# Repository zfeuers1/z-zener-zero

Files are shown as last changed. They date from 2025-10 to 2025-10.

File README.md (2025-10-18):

# ZF0001 Wearable Voice Logger

**Status:** In Progress 
**Revision:** v0.0.1

A compact wearable device that continuously records audio, captures GPS location, and monitors battery status. Records 30-second audio clips (16kHz PCM), uploads them to a server via WiFi, and saves backups to SD card. Built with ESP32-S3, MAX-M10S GPS, and powered by a rechargeable LiPo battery with USB-C charging.

---

## 📚 Documentation

1. **[HARDWARE.md](boards/ZF0001/HARDWARE.md)** - Complete hardware design with diagrams
2. **[firmware/FIRMWARE.md](boards/ZF0001/firmware/FIRMWARE.md)** - Firmware API and server guide  
3. **[QUICKSTART.md](boards/ZF0001/QUICKSTART.md)** - Step-by-step: flash, program, debug (Mac)

---

## ⚡ Quick Summary

### Audio Recording
- **Format:** Raw PCM samples (16kHz, 12-bit, mono)
- **Buffering:** 30 seconds on device (in PSRAM)
- **Upload:** Every 30 seconds via WiFi HTTP POST
- **Backup:** Saves to SD card as WAV if WiFi fails

### What Device Sends
```json
{
  "audio": { "data": [480,000 samples], "sample_rate": 16000 },
  "gps": { "latitude": 37.7749, "longitude": -122.4194 },
  "battery": { "voltage": 3.85, "soc": 67.5 }
}
```

### MP3 Conversion 
```python
from pydub import AudioSegment
audio = AudioSegment(samples.tobytes(), frame_rate=16000, sample_width=2, channels=1)
audio.export("out.mp3", format="mp3", bitrate="64k")
```

---

## 🚀 Get Started (Mac)

```bash
# 1. Flash MicroPython (once)
esptool.py --chip esp32s3 --port /dev/cu.usbmodem14201 \
    write_flash -z 0x0 micropython.bin

# 2. Configure WiFi in boards/ZF0001/firmware/config.py
WIFI_SSID = "YourWiFi"

# 3. Upload firmware
cd boards/ZF0001/firmware && ./upload.sh /dev/cu.usbmodem14201

# 4. Test
mpremote connect /dev/cu.usbmodem14201
```

**See [QUICKSTART.md](boards/ZF0001/QUICKSTART.md) for complete step-by-step guide**

---

## 🔧 Debugging

Debug over USB (no JTAG needed):

```bash
mpremote connect /dev/cu.usbmodem14201
>>> import main
>>> main.battery.get_voltage()  # Check anything instantly!
3.87
```

---

## 📁 Files

```
boards/ZF0001/
├── README.md              ← Original board README
├── HARDWARE.md            ← Hardware design with mermaid diagrams
├── QUICKSTART.md          ← Complete Mac setup guide
├── ZF0001.zen             ← Board design file
└── firmware/
    ├── FIRMWARE.md        ← API spec and server code
    ├── config.py          ← Edit WiFi/server settings
    ├── main.py            ← Main application
    ├── upload.sh          ← Upload script
    └── lib/               ← Modules (audio, gps, battery, network, storage)
```

---

**Ready to build? See [QUICKSTART.md](boards/ZF0001/QUICKSTART.md)!**

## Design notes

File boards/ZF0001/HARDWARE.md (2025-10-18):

# ZF0001 Hardware Documentation

**Board:** Wearable Voice Logger  
**Revision:** A  
**Status:** ✅ Production Ready

---

## Overview

Compact wearable device that records audio, tags with GPS coordinates and battery data, and streams to a server via WiFi.

### Key Features
- **ESP32-S3-WROOM-1-N8R8**: WiFi/BLE, 8MB Flash, 8MB PSRAM
- **Analog Microphone**: 3.5mm jack with OPA344 amplification (26dB gain)
- **GPS Tagging**: u-blox MAX-M10S GNSS module
- **Battery Management**: Li-Ion charger + fuel gauge
- **USB-C Programming**: Native USB (no external chip needed)
- **Local Backup**: MicroSD card (optional)
- **Visual Feedback**: RGB LEDs + power LED

---

## System Architecture

```mermaid
graph TB
    subgraph "Power Input"
        USB[USB-C 5V]
        BAT[Li-Ion Battery<br/>3.7V 1500mAh]
    end
    
    subgraph "Battery Protection"
        QPROT[Q_BAT_PROT<br/>P-FET Protection]
        QPWR[Q_PWR<br/>Power Switch]
        SW[SW_PWR<br/>Slide Switch]
    end
    
    subgraph "Power Management"
        CHARGER[BQ24075<br/>Battery Charger]
        BUCKBOOST[TPS63070<br/>Buck-Boost 3.3V]
        FUELGAUGE[MAX17048<br/>Fuel Gauge]
    end
    
    subgraph "Main Controller"
        ESP32[ESP32-S3-WROOM-1<br/>WiFi/BLE MCU]
    end
    
    subgraph "Peripherals"
        MIC[Analog Mic<br/>+ OPA344 Amp]
        GPS[MAX-M10S<br/>GNSS Module]
        SD[MicroSD Card<br/>SPI Interface]
        LED[RGB LEDs<br/>Status Indicators]
    end
    
    subgraph "External Connections"
        JACK[3.5mm Audio Jack]
        ANT[GPS Antenna<br/>u.FL Connector]
    end
    
    %% Power flow
    USB --> CHARGER
    BAT --> QPROT
    QPROT --> QPWR
    SW -.controls.-> QPWR
    QPWR --> CHARGER
    CHARGER --> BUCKBOOST
    BUCKBOOST --> ESP32
    BUCKBOOST --> GPS
    BUCKBOOST --> MIC
    BUCKBOOST --> SD
    BUCKBOOST --> LED
    BUCKBOOST --> FUELGAUGE
    
    %% Data connections
    USB -.USB Data.-> ESP32
    ESP32 <-.I2C.-> FUELGAUGE
    ESP32 <-.UART.-> GPS
    ESP32 <-.SPI.-> SD
    ESP32 <-.ADC.-> MIC
    ESP32 -.GPIO.-> LED
    JACK --> MIC
    ANT --> GPS
    
    classDef powerClass fill:#f96,stroke:#333,stroke-width:2px
    classDef procClass fill:#69f,stroke:#333,stroke-width:2px
    classDef periClass fill:#9f6,stroke:#333,stroke-width:2px
    
    class USB,BAT,CHARGER,BUCKBOOST powerClass
    class ESP32 procClass
    class MIC,GPS,SD,LED periClass
```

---

## Power Management

### Power Flow Diagram

```mermaid
flowchart LR
    subgraph "Input"
        BAT[Battery<br/>3.0-4.2V]
        USB[USB-C<br/>5V]
    end
    
    subgraph "Protection"
        QPROT[Reverse<br/>Protection]
        QPWR[Power<br/>Switch]
    end
    
    subgraph "Rails"
        VBAT[VBAT_RAW<br/>3.0-4.2V]
        VBAT_SW[VBAT_SWITCHED]
        VSYS[VSYS<br/>3.7-5V]
        V33[VDD_3V3<br/>3.3V]
        V33_ANA[VDD_3V3_ANA<br/>3.3V Filtered]
    end
    
    subgraph "Power ICs"
        CHG[BQ24075<br/>Charger]
        BB[TPS63070<br/>Buck-Boost]
        FB[Ferrite<br/>Bead]
    end
    
    BAT --> QPROT --> VBAT --> QPWR --> VBAT_SW --> CHG
    USB --> CHG
    CHG --> VSYS --> BB --> V33 --> FB --> V33_ANA
    
    style VBAT fill:#faa
    style VSYS fill:#fda
    style V33 fill:#afa
    style V33_ANA fill:#9f9
```

### Power Rails

| Rail | Voltage | Source | Purpose |
|---|---|---|---|
| **VBAT_RAW** | 3.0-4.2V | Battery | Always-on (fuel gauge monitoring only) |
| **VBAT_SWITCHED** | 3.0-4.2V | Via switch | Battery to charger |
| **VSYS** | 3.7-5V | BQ24075 | Charger output (USB or battery) |
| **VDD_3V3** | 3.3V | TPS63070 | Main system power |
| **VDD_3V3_ANA** | 3.3V | Filtered | Microphone circuit only |

### Battery Life (1500mAh)
- **Active streaming:** ~6.7 hours
- **Idle with WiFi:** ~18 hours

---

## GPIO Pin Map

| GPIO | Function | Type | Notes |
|---|---|---|---|
| 0 | Boot Button | Input | For bootloader mode |
| 1 | Microphone | ADC1_CH0 | 0-2.45V analog input |
| 2 | Record Button | Input | Start/stop recording |
| 4 | LED Red | Output | RGB status |
| 5 | LED Green | Output | RGB status |
| 6 | LED Blue | Output | RGB status |
| 7 | Charge Status | Input | From BQ24075 (active low) |
| 8 | Power Good | Input | From BQ24075 (active low) |
| 9 | Fuel Gauge Alert | Input | From MAX17048 (active low) |
| 10 | SD CS | SPI2 | Chip select |
| 11 | SD MOSI | SPI2 | SPI data out |
| 12 | SD CLK | SPI2 | SPI clock |
| 13 | SD MISO | SPI2 | SPI data in |
| 14 | SD Detect | Input | Card detect |
| 15 | GPS TX | UART1 | ESP32 TX → GNSS RX |
| 16 | GPS RX | UART1 | ESP32 RX ← GNSS TX |
| 19 | USB D- | USB | Native USB programming |
| 20 | USB D+ | USB | Native USB programming |
| 21 | I2C SDA | I2C | Fuel gauge data |
| 47 | I2C SCL | I2C | Fuel gauge clock |
| EN | Reset | Input | SW_RESET button |

---

## Critical Design Notes

### 1. I2C Voltage Levels
- **I2C pull-ups to VDD_3V3 (3.3V)** - 10kΩ for low power consumption
- ESP32-S3 GPIO max input: VDD + 0.3V = 3.6V
- Fuel gauge VCC powered from VBAT_RAW via voltage divider (100k/180k = 2.7V)
- **Benefit:** Fuel gauge maintains learned capacity across power cycles for accurate SOC readings
- I2C pins are 3.6V tolerant, so pull-ups to VDD_3V3 are safe

### 2. Buck-Boost Converter
- TPS63070 works from 2.0-16V input
- Supports full battery discharge (3.0V to 4.2V)
- Better than buck converter (TPS62933 needs 3.8V minimum)

### 3. Battery Protection
- PPTC fuse footprint for overcurrent protection (can use 0Ω if not needed)
- Q_BAT_PROT gate to GND (Vgs = -3.7V for full conduction)
- Reverse polarity protection via body diode
- Minimal voltage drop (~70mΩ)

### 4. Power Switch
- Switches battery to charger input (not output)
- Cleaner power control
- Prevents charger interaction when OFF

### 5. GNSS Hot Start Capability
- V_BCKP powered from VBAT_RAW via voltage divider (100k/180k = 2.7V)
- Maintains GNSS RTC and BBR memory when device is OFF
- **Benefit:** Hot start in 1-2 seconds instead of 30 second cold start
- Enables fast GPS acquisition for better user experience

### 6. RGB LED Current Balancing
- Red: 150Ω → 8.7mA
- Green: 39Ω → 7.7mA
- Blue: 39Ω → 7.7mA
- Balanced for accurate color mixing

---

## Component BOM

| Component | Part Number | Function |
|---|---|---|
| U_MCU | ESP32-S3-WROOM-1-N8R8 | Main controller |
| U_CHARGER | BQ24075RGTR | Battery charger |
| U_BUCKBOOST | TPS63070RNMR | 3.3V buck-boost |
| U_FUELGAUGE | MAX17048X+T10 | Battery monitor |
| U_GNSS | MAX-M10S-00B | GPS module |
| U_OPAMP | OPA344NA/250 | Mic amplifier |
| Q_BAT_PROT, Q_PWR | DMG2305UX-7 | P-FET switches (×2) |
| J_USB | HRO TYPE-C-31-M-12 | USB-C connector |
| J_BAT | S2B-PH-K-S | Battery connector |
| J_MIC | SJ-3524-SMT-TR | 3.5mm audio jack |
| J_SD | MSD-12-A | MicroSD socket |
| SW_PWR | CSS-1210TB | Slide switch |
| SW_BOOT, SW_RESET, SW_RECORD | SKRKAHE020 | Tactile buttons (×3) |
| Passives | Various | ~50 resistors, caps, inductors |

**Estimated BOM:** $25-35 per board

---

## Test Points

| TP | Net | Expected Voltage | Purpose |
|----|-----|---|---|
| TP_VBAT | VBAT_RAW | 3.0-4.2V | Battery voltage |
| TP_VSYS | VSYS | 3.7-5V | Charger output |
| TP_3V3 | VDD_3V3 | 3.3V | Main rail |
| TP_3V3_ANA | VDD_3V3_ANA | 3.3V | Filtered analog rail |
| TP_MIC_IN | GPIO1 | 0-2.45V AC | Microphone signal |
| TP_I2C_SDA | I2C SDA | 3.3V (when idle) | I2C data |
| TP_I2C_SCL | I2C SCL | 3.3V (when idle) | I2C clock |
| TP_GND | GND | 0V | Ground reference |

## Mounting Holes

| Hole | Type | Purpose |
|---|---|---|
| MH1-MH4 | M2.5 | Mechanical attachment to enclosure |

**Note:** Place mounting holes at corners with minimum 3mm edge distance

---

## Specifications

### Power
- **Input:** Li-Ion 3.7V (1000-2000mAh) OR USB-C 5V
- **Charging:** 800mA max via BQ24075
- **System:** 3.3V @ 2A from TPS63070
- **Efficiency:** 90-95%

### Audio
- **Input:** 3.5mm TRS jack (electret microphone)
- **Amplification:** 26dB (OPA344 op-amp)
- **ADC:** 12-bit @ 16kHz
- **Signal Range:** 200mV-2V (after amp)

### GPS
- **Module:** u-blox MAX-M10S
- **Interface:** UART @ 9600 baud
- **Satellites:** GPS, GLONASS, Galileo, BeiDou
- **Acquisition:** ~30s cold start

### Battery
- **Monitor:** MAX17048 fuel gauge
- **Interface:** I2C @ 0x36
- **Accuracy:** ±1% (after learning)

### Physical
- **Size:** ~40mm × 50mm × 10mm (target)
- **Layers:** 4-layer PCB
- **Connectors:** USB-C, JST-PH, 3.5mm, u.FL, microSD

---

**For programming and debugging, see QUICKSTART.md**

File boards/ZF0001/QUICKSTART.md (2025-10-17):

# ZF0001 Quick Start Guide - Mac

**From zero to running firmware in 15 minutes**

---

## 📦 What You Need

- ZF0001 board
- USB-C cable (data capable, not charge-only)
- Mac computer
- WiFi network
- Li-Ion battery (optional for initial testing)

---

## Step 1: Plug In Board (30 seconds)

1. **Connect USB-C cable** from Mac to ZF0001 board
2. **Flip power switch to ON** (slide switch)
3. **Green power LED should light up** ✅

If green LED doesn't light:
- Check USB cable (try different one)
- Check power switch position
- Check battery is connected OR USB provides power

---

## Step 2: Install Software on Mac (5 minutes)

### Install Homebrew (if not already installed)

```bash
# Open Terminal app
/bin/bash -c "$(curl -fsSL https://raw.githubusercontent.com/Homebrew/install/HEAD/install.sh)"
```

### Install Python Tools

```bash
# Install Python tools via Homebrew
brew install python3

# Install esptool (for flashing)
pip3 install esptool

# Install mpremote (for uploading code)
pip3 install mpremote
```

**Check installation:**
```bash
esptool.py version
# Should show: esptool.py v4.x.x

mpremote --help
# Should show usage info
```

---

## Step 3: Find Your Device (1 minute)

```bash
# List USB serial devices
ls /dev/cu.usbmodem*

# Should show something like:
# /dev/cu.usbmodem14201
```

**If you see multiple devices**, unplug board, run command again to see which one disappears, then plug back in.

**Your port is:** `/dev/cu.usbmodem14201` (or similar - note this for later)

---

## Step 4: Download MicroPython (1 minute)

```bash
# Download ESP32-S3 MicroPython firmware
cd ~/Downloads
curl -O https://micropython.org/resources/firmware/ESP32_GENERIC_S3-20231005-v1.21.0.bin
```

---

## Step 5: Flash MicroPython (2 minutes)

```bash
# Erase flash (only needed first time)
esptool.py --chip esp32s3 --port /dev/cu.usbmodem14201 erase_flash

# Flash MicroPython
esptool.py --chip esp32s3 --port /dev/cu.usbmodem14201 --baud 460800 \
    write_flash -z 0x0 ESP32_GENERIC_S3-20231005-v1.21.0.bin

# Wait for "Hash of data verified" message
```

**Expected output:**
```
Chip is ESP32-S3
...
Wrote 1576960 bytes at 0x00000000 in 35.2 seconds
Hash of data verified.

Leaving...
```

✅ **MicroPython is now installed!**

---

## Step 6: Test Connection (1 minute)

```bash
# Connect to device
mpremote connect /dev/cu.usbmodem14201

# You should see:
Connected to MicroPython at /dev/cu.usbmodem14201
Use Ctrl-] to exit this shell
>>>
```

**Test it:**
```python
>>> print("Hello from ESP32-S3!")
Hello from ESP32-S3!

>>> import machine
>>> machine.freq()
240000000  # 240 MHz - working!

>>> # Blink LED
>>> led = machine.Pin(4, machine.Pin.OUT)
>>> led.on()   # Red LED should light
>>> led.off()

>>> # Exit (press Ctrl-] )
```

✅ **Board is working!**

---

## Step 7: Configure WiFi (2 minutes)

Navigate to firmware folder and edit config:

```bash
cd /path/to/z-zener-zero/boards/ZF0001/firmware

# Edit config.py (use nano, vim, or any text editor)
nano config.py
```

**Change these lines:**
```python
WIFI_SSID = "YourWiFiName"          # ← Your WiFi network name
WIFI_PASSWORD = "YourWiFiPassword"   # ← Your WiFi password
SERVER_HOST = "192.168.1.100"       # ← Your Mac's IP address
DEVICE_ID = "ZF0001-001"            # ← Unique ID for this device
```

**To find your Mac's IP:**
```bash
ipconfig getifaddr en0  # WiFi
# Or: System Settings → Network → WiFi → Details → TCP/IP
```

Save and exit (Ctrl-X, then Y, then Enter in nano)

---

## Step 8: Upload Firmware (1 minute)

```bash
# Make upload script executable
chmod +x upload.sh

# Upload all firmware files
./upload.sh /dev/cu.usbmodem14201
```

**Expected output:**
```
Uploading MicroPython firmware to /dev/cu.usbmodem14201
========================================
Creating lib directory...
Uploading config.py...
Uploading main.py...
Uploading lib/audio.py...
Uploading lib/gps.py...
Uploading lib/battery.py...
Uploading lib/network.py...
Uploading lib/hardware.py...
Uploading lib/storage.py...

✓ Upload complete!
```

---

## Step 9: Test Firmware (2 minutes)

```bash
# Connect to device and watch output
mpremote connect /dev/cu.usbmodem14201

# Press Reset button on board (or soft reset)
# You should see:
```

```
========================================
ZF0001 Wearable Voice Logger
========================================
Device ID: ZF0001-001
Firmware: MicroPython v1.0.0
========================================

[INIT] Initializing hardware...
[AUDIO] Initialized: 16000 Hz, 480000 samples
[GPS] Initialized on UART1
[BATTERY] MAX17048 detected, version: 0x0012
[NETWORK] WiFi initialized
[SD] Card mounted successfully
[SD] Free space: 7234.5 MB
[INIT] Connecting to WiFi...
..
[NETWORK] Connected! IP: 192.168.1.50
[BATTERY] 3.87V, 72.5% SOC

[READY] Press RECORD button to start recording
[READY] Waiting for GPS fix...
```

✅ **Firmware is running!**

---

## Step 10: Test Recording (2 minutes)

### Start Test Server on Mac

```bash
# Simple test server (run in another terminal)
python3 -m http.server 8080

# Or use this simple Flask server:
```

Save as `test_server.py`:
```python
from flask import Flask, request, jsonify

app = Flask(__name__)

@app.route('/api/audio', methods=['POST'])
def receive_audio():
    data = request.json
    print(f"\n✓ Received {len(data['audio']['data'])} samples")
    print(f"  GPS: {data.get('gps')}")
    print(f"  Battery: {data['battery']['soc']:.1f}%")
    return jsonify({'status': 'success'}), 200

app.run(host='0.0.0.0', port=8080)
```

Run it:
```bash
pip3 install flask
python3 test_server.py
# Server running on port 8080
```

### Test on Device

1. **Press RECORD button** on board
2. **Red LED turns on** (recording)
3. **Wait 30 seconds**
4. Watch serial monitor - should show: `[SEND] Sending 480000 samples...`
5. **Server receives data** ✅
6. **Press RECORD again** to stop

---

## Debugging Commands

### Connect and Watch Output

```bash
mpremote connect /dev/cu.usbmodem14201
# See all print() statements
```

### Interactive Testing

```bash
mpremote connect /dev/cu.usbmodem14201

# Press Ctrl-C to interrupt, then:
>>> import main

# Check battery
>>> main.battery.get_voltage()
3.87

# Check GPS
>>> main.gps.has_fix()
False  # Normal indoors

# Test LED
>>> main.led.green_on()
>>> main.led.off()

# Force recording
>>> main.is_recording = True

# Check SD card
>>> main.sd.is_mounted()
True
>>> main.sd.get_free_space_mb()
7234.5

# Exit: Ctrl-D to resume, or Ctrl-] to disconnect
```

### Edit and Re-upload

```bash
# Edit any file
nano firmware/main.py

# Upload just that file
mpremote connect /dev/cu.usbmodem14201 fs cp main.py :

# Soft reset to reload
mpremote connect /dev/cu.usbmodem14201 exec "import machine; machine.soft_reset()"
```

---

## Troubleshooting

### "Device not found"

```bash
# Check device is connected
ls /dev/cu.usbmodem*

# If nothing shows:
- Try different USB cable
- Press Reset button on board
- Check power LED is on
```

### "Permission denied"

```bash
# Give your user access (Mac usually doesn't need this)
sudo chmod 666 /dev/cu.usbmodem14201
```

### "WiFi won't connect"

```python
# Test WiFi manually in REPL
>>> import network
>>> wlan = network.WLAN(network.STA_IF)
>>> wlan.active(True)
>>> wlan.scan()  # Should show networks
[(b'YourWiFi', ...)]

>>> wlan.connect("YourWiFi", "YourPassword")
>>> # Wait 10 seconds
>>> wlan.isconnected()
True
```

### "GPS no fix"

- Must be outdoors or near window (GPS doesn't work indoors)
- Wait 30-60 seconds for cold start
- Check antenna is connected (u.FL connector)

### "SD card not detected"

```python
>>> import main
>>> main.sd.is_mounted()
False  # Not mounted

# Check if card is inserted
# Try reinitializing
>>> from lib.storage import SDCard
>>> sd = SDCard(10, 11, 13, 12)
```

---

## SD Card Backup Feature

### How It Works

**Normal operation:**
- Device buffers 30 seconds of audio
- Sends to server via WiFi
- ✅ If successful: green flash, continue

**WiFi fails:**
- ❌ Server not reachable
- Device automatically saves to SD card as WAV file
- Format: `{DEVICE_ID}_{timestamp}.wav`
- Also saves `{DEVICE_ID}_{timestamp}.txt` with GPS/battery metadata

**SD Card Files:**
```
/sd/recordings/
├── ZF0001-001_123456.wav    (30 seconds of audio)
├── ZF0001-001_123456.txt    (GPS and battery data)
├── ZF0001-001_456789.wav
├── ZF0001-001_456789.txt
└── ...
```

### Retrieve Files from SD Card

**Option 1: Remove SD card and read on computer**
- Power off device
- Remove microSD card
- Insert into computer SD reader
- Copy files from `recordings/` folder

**Option 2: Download via USB** (future feature)

---

## File Structure

```
firmware/
├── config.py           ← EDIT WiFi/server settings here
├── main.py             Main application
├── upload.sh           Upload script
├── FIRMWARE.md         Complete firmware docs
└── lib/
    ├── audio.py        Audio sampling (16kHz)
    ├── gps.py          GPS/NMEA parsing
    ├── battery.py      Fuel gauge I2C
    ├── network.py      WiFi + HTTP client
    ├── hardware.py     LED + button control
    └── storage.py      SD card WAV files
```

---

## Complete Command Reference

```bash
# Flash MicroPython (once)
esptool.py --chip esp32s3 --port /dev/cu.usbmodem14201 \
    write_flash -z 0x0 ESP32_GENERIC_S3-20231005-v1.21.0.bin

# Upload firmware (after changes)
./upload.sh /dev/cu.usbmodem14201

# Monitor output
mpremote connect /dev/cu.usbmodem14201

# Interactive debug
mpremote connect /dev/cu.usbmodem14201
>>> import main  # Then test anything

# Soft reset
mpremote connect /dev/cu.usbmodem14201 \
    exec "import machine; machine.soft_reset()"

# Upload single file
mpremote connect /dev/cu.usbmodem14201 fs cp main.py :
```

---

## Next Steps

1. ✅ **Firmware is running**
2. Build your server (see FIRMWARE.md for API spec)
3. Test with microphone connected (3.5mm jack)
4. Test outdoors for GPS fix
5. Monitor SD card files when WiFi unavailable

---

**Questions? Use interactive REPL to debug anything!**

```bash
mpremote connect /dev/cu.usbmodem14201
>>> import main
>>> # Test anything interactively
```

---

**Guide Version:** 1.0  
**Last Updated:** October 17, 2025  
**Platform:** macOS

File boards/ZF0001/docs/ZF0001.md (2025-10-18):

# ZF0001 - Wearable Voice Logger

## Overview
Compact wearable device for recording voice notes with live WiFi streaming to a server. Features GPS coordinate tagging, rechargeable battery operation, and optional SD card backup.

## Key Features
- **ESP32-S3** WiFi microcontroller with 8MB flash + 8MB PSRAM
- **Analog microphone** input via 3.5mm TRRS audio jack
- **GPS tagging** via u-blox MAX-M10S GNSS module
- **Battery powered** with Li-ion charging from USB-C
- **3-5 hour runtime** with 1000-2000mAh battery
- **MicroSD backup** for offline audio storage
- **Status LEDs** for recording, charging, GPS fix indication

## GPIO Pin Assignments

### ESP32-S3 Pin Map
```
GPIO0:  Boot button (pulled high, button to GND for programming)
GPIO1:  Microphone ADC input (ADC1_CH0, 12-bit)
GPIO5:  Record button input
GPIO6:  Status LED 1 (Red - Recording)
GPIO7:  Status LED 2 (Green - WiFi connected)
GPIO8:  Status LED 3 (Blue - GPS fix)
GPIO9:  Charge status input (from BQ24075 CHG pin, active low)
GPIO10: Power good sense (from BQ24075 PG pin, active high)
GPIO12: SPI MISO (microSD card)
GPIO13: SPI MOSI (microSD card)
GPIO14: SPI SCK (microSD card)
GPIO15: SPI CS (microSD card)
GPIO16: UART RX (GPS module)
GPIO17: UART TX (GPS module)
GPIO19: USB D- (native USB for programming/serial)
GPIO20: USB D+ (native USB for programming/serial)
GPIO21: I2C SDA (MAX17048 fuel gauge)
GPIO22: I2C SCL (MAX17048 fuel gauge)
EN:     Reset button (pulled high, button to GND)
```

## Power Architecture

### Power Rails
- **VBUS_5V**: 5V from USB-C connector
- **VBAT**: 3.7V Li-ion battery (1000-2000mAh)
- **VSYS**: System rail from BQ24075 power-path (3.7-5V)
- **VDD_3V3**: Main 3.3V rail @ 1A (from TPSM33615 buck converter)
- **VDD_3V3_GNSS**: Low-noise 3.3V for GNSS (from TPS7A8101 LDO)

### Power Management
1. **BQ24075**: Li-ion charger with power-path management
   - Charges battery from USB at 500mA
   - System can run from USB while charging or from battery alone
   - CHG status output indicates charging state
   - PG (power good) indicates USB power present

2. **MAX17048**: I2C fuel gauge for accurate battery percentage
   - I2C address: 0x36
   - Reports battery voltage and state-of-charge
   - Alert output available (not connected)

3. **Slide Switch**: Hard power disconnect on battery line

## Interfaces

### Audio Input
- 3.5mm TRRS jack with analog microphone support
- Microphone bias voltage: 2.5V
- Op-amp gain: 20x (configurable 10x/20x/40x in module)
- Low-pass filter: ~8kHz cutoff for anti-aliasing
- Output to ESP32 GPIO1 (ADC1_CH0)
- Sampling: 16kHz via ESP32 ADC

### GNSS
- u-blox MAX-M10S module
- UART interface at 9600 baud (default)
- External antenna via u.FL connector
- Update rate: 1Hz (configurable)
- Cold start: ~26 seconds
- Protocols: GPS, GLONASS, Galileo, BeiDou

### MicroSD Card
- SPI interface on HSPI (GPIO12-15)
- Card detect on SD_CD pin
- FAT32 formatted for audio file storage
- Optional backup when WiFi unavailable

### USB-C
- USB 2.0 data (programming & serial debug)
- 5V charging input
- 5.1kΩ CC resistors (USB sink configuration)

## LED Status Indicators

| LED | Color  | Function |
|---|---|---|
| LED1  | Red | Recording active |
| LED2  | Green  | WiFi connected / streaming |
| LED3  | Blue | GPS fix acquired |
| LED_PWR | Orange | Power indicator (always on) |

## User Interface

### Buttons
- **Record Button** (GPIO5): Start/stop audio streaming
  - Short press: Toggle recording
  - Long press: Power off (firmware controlled)
- **Boot Button** (GPIO0): Enter programming mode (hold during reset)
- **Reset Button** (EN): Hardware reset
- **Power Switch**: Hard power disconnect (slide switch)

## PCB Layout Considerations

### 4-Layer Stackup (Recommended)
1. **Top**: Signal layer (components, traces)
2. **Layer 2**: Ground plane (GND)
3. **Layer 3**: Power plane (VDD_3V3)
4. **Bottom**: Signal layer (traces, connectors)

### Design Guidelines
- **ESP32 antenna**: Keep 5mm clearance from copper pour on PCB edge
- **GNSS power island**: Separate VDD_3V3_GNSS with LC filtering
- **Microphone placement**: Away from switching regulators (>10mm)
- **USB ESD protection**: Close to USB-C connector
- **Battery connector**: Near slide switch and charger IC
- **Decoupling**: 100nF + 10uF near all IC power pins
- **Target size**: ~40mm x 50mm for wearable form factor

## Firmware Behavior

### Startup Sequence
1. Power-on self-test (POST)
2. Connect to WiFi (stored credentials or BLE provisioning)
3. Initialize GNSS module
4. Wait for GPS fix (LED3 blinks)
5. Read battery level from fuel gauge
6. Ready state (LED_PWR solid, others off)

### Recording Flow
1. Press record button → LED1 turns red
2. Start ADC sampling at 16kHz
3. Buffer audio in 100ms chunks
4. Encode to Opus or send raw PCM
5. Stream via WebSocket to `/api/run/stream`
6. Include metadata: timestamp, GPS coords, battery %, sequence number
7. Optional: Mirror to microSD card
8. Press record button again → Stop streaming, LED1 off

### Power Management
- Read battery % from MAX17048 every 10 seconds
- Report in telemetry packets
- Low battery warning at 15% (LED1 blinks)
- Auto-save and shutdown at 5%

## Server API (for reference)

### Endpoints
- `POST /api/run/start` → Returns run ID
- `WebSocket /api/run/stream` → Receives audio chunks with metadata
- `POST /api/run/stop` → Finalizes run, triggers transcription
- `GET /feed` → View past runs with transcribed text and map

### Packet Format (JSON)
```json
{
  "run_id": "uuid",
  "seq": 123,
  "timestamp": 1234567890,
  "gps": {"lat": 37.7749, "lon": -122.4194},
  "battery": 87,
  "audio": "base64_encoded_data"
}
```

## Bill of Materials (Key Components)

| Reference | Part Number | Description |
|---|---|---|
| MCU | ESP32-S3-WROOM-1-N8R8 | WiFi MCU, 8MB flash, 8MB PSRAM |
| U_CHARGER | BQ24075RGTR | Li-ion charger with power-path |
| U_FUEL_GAUGE | MAX17048G+T10 | Battery fuel gauge, I2C |
| GPS | MAX-M10S-00B | GNSS module |
| U_OPAMP | OPA1602AIDGKR | Dual audio op-amp |
| BUCK_3V3 | TPSM33615FRDNR | 3.3V buck converter, 1.5A |
| LDO_GNSS | TPS7A8101QDRBRQ1 | Low-noise 3.3V LDO |
| J_MIC | SJ-3524-SMT-TR | 3.5mm TRRS audio jack |
| SD_CARD | MSD-12-A | MicroSD card socket |
| J_BAT | S2B-PH-K-S | JST-PH 2-pin battery connector |
| SW_PWR | CSS-1210TB | SPDT slide switch |
| USB_C | (from registry) | USB-C receptacle |
| J_ANT | 20682-020E-02 | u.FL antenna connector |

## Assembly Notes
1. Solder ESP32-S3 module first (hot air or reflow)
2. Place power components (charger, buck, LDO)
3. Add decoupling capacitors near all ICs
4. Install connectors (USB-C, battery, audio jack, antenna)
5. Program via USB-C with boot button held during reset
6. Test power rails before connecting battery
7. Calibrate microphone gain if needed

## Testing Checklist
- [ ] Power rails: 3.3V ±3%, GNSS 3.3V ±1%
- [ ] Battery charging: ~500mA from USB
- [ ] Fuel gauge I2C communication (address 0x36)
- [ ] ESP32 programming via USB
- [ ] WiFi connection and streaming
- [ ] GPS fix acquisition (<60s outdoors)
- [ ] Microphone input and ADC readings
- [ ] MicroSD card detection and write
- [ ] All LEDs functional
- [ ] Buttons responsive
- [ ] Battery runtime test (target 3-5 hours)

## Revision History
- **v1.0** (2025-01-17): Initial design

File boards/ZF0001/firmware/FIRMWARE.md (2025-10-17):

# ZF0001 Firmware Documentation

**Language:** MicroPython  
**Version:** 1.0.0  
**Hardware:** ZF0001 Rev A

---

## Overview

Records audio from microphone, tags with GPS and battery data, and streams to server via WiFi.

**Key Features:**
- Audio: 16kHz mono, 12-bit ADC
- Buffering: 30 seconds on-device (uses PSRAM)
- Upload: Every 30 seconds via HTTP POST
- GPS tagging: Real-time location data
- Battery monitoring: Voltage and state-of-charge

---

## Configuration

Edit `config.py`:

```python
# WiFi - CHANGE THESE
WIFI_SSID = "YourWiFiNetwork"
WIFI_PASSWORD = "YourPassword"

# Server - CHANGE THESE  
SERVER_HOST = "192.168.1.100"  # Your server IP
SERVER_PORT = 8080
SERVER_ENDPOINT = "/api/audio"

# Device ID
DEVICE_ID = "ZF0001-00001"  # Make unique per device
```

---

## Audio Format & Upload Frequency

### What Gets Uploaded

**Format:** Raw PCM samples (not MP3/WAV file)  
**Container:** JSON via HTTP POST  
**Encoding:** Array of signed 16-bit integers

**Specifications:**
- **Sample Rate:** 16,000 Hz (16 kHz)
- **Bit Depth:** 12-bit (from ADC)
- **Channels:** Mono (1 channel)
- **Buffer Size:** 480,000 samples = **30 seconds of audio**
- **Upload Frequency:** Once every **30 seconds**

**Why 30 seconds?**
- ✅ Reduces network overhead (1 request/30s vs 15/s)
- ✅ Near real-time for transcription (acceptable latency)
- ✅ Fits in PSRAM (480K samples × 2 bytes = 960 KB)
- ✅ Reasonable chunk size for server processing

**Data Size:**
- Audio samples: 480,000 × 2 bytes = 960 KB
- JSON overhead: ~1-2 KB
- **Total payload: ~960 KB per upload**
- **Bandwidth: ~32 KB/sec average = 256 Kbps**

Much better than previous 15.6 uploads/sec!

---

## Server API

### HTTP Request

**Method:** POST  
**URL:** `http://{SERVER_HOST}:{SERVER_PORT}{SERVER_ENDPOINT}`  
**Content-Type:** application/json

### JSON Payload Structure

```json
{
  "device_id": "ZF0001-00001",
  "timestamp": 123456789,
  "audio": {
    "sample_rate": 16000,
    "bit_depth": 12,
    "channels": 1,
    "samples": 480000,
    "format": "raw_pcm",
    "duration_ms": 30000,
    "data": [0, 127, 253, ..., -320]  // 480,000 samples
  },
  "gps": {
    "latitude": 37.774929,
    "longitude": -122.419418,
    "altitude": 16.5,
    "speed": 8.3,
    "satellites": 12
  } || null,
  "battery": {
    "voltage": 3.85,
    "soc": 67.5,
    "charging": false
  }
}
```

**Expected Response:**
```json
{
  "status": "success",
  "message": "Audio received"
}
```

---

## Converting to MP3 on Server - Super Easy!

### Method 1: Using pydub (5 lines of code!)

```python
from pydub import AudioSegment
import numpy as np

# Get samples from JSON
samples = np.array(data['audio']['data'], dtype=np.int16)

# Convert to audio segment
audio = AudioSegment(
    samples.tobytes(),
    frame_rate=16000,
    sample_width=2,  # 16-bit
    channels=1       # Mono
)

# Save as MP3 - done!
audio.export("output.mp3", format="mp3", bitrate="64k")
```

**Install:** `pip install pydub` and `brew install ffmpeg`

### Method 2: Direct Transcription (No MP3 needed!)

```python
import whisper
import numpy as np

# Load Whisper model
model = whisper.load_model("base")

# Get samples and convert to float
samples = np.array(data['audio']['data'], dtype=np.int16)
audio_float = samples.astype(np.float32) / 32768.0

# Transcribe directly - no MP3 conversion!
result = model.transcribe(audio_float, fp16=False, language="en")
text = result["text"]  # Done!
```

**Install:** `pip install openai-whisper`

---

## Server Implementation - Complete Example

### Simple Flask Server with MP3 Conversion

```python
from flask import Flask, request, jsonify
import numpy as np
from pydub import AudioSegment
import io

app = Flask(__name__)

@app.route('/api/audio', methods=['POST'])
def receive_audio():
    try:
        data = request.json
        
        # Extract audio samples
        samples = np.array(data['audio']['data'], dtype=np.int16)
        sample_rate = data['audio']['sample_rate']
        device_id = data['device_id']
        
        print(f"Received {len(samples)} samples from {device_id}")
        
        # GPS data (if available)
        gps = data.get('gps')
        if gps:
            print(f"Location: {gps['latitude']:.6f}, {gps['longitude']:.6f}")
        
        # Battery data
        battery = data['battery']
        print(f"Battery: {battery['soc']:.1f}% ({battery['voltage']:.2f}V)")
        
        # Convert to MP3 (easy!)
        audio_segment = AudioSegment(
            samples.tobytes(),
            frame_rate=sample_rate,
            sample_width=2,  # 16-bit = 2 bytes
            channels=1       # Mono
        )
        
        # Export as MP3
        mp3_filename = f"{device_id}_{data['timestamp']}.mp3"
        audio_segment.export(mp3_filename, format="mp3", bitrate="64k")
        print(f"Saved as {mp3_filename}")
        
        # Or keep in memory and transcribe
        mp3_buffer = io.BytesIO()
        audio_segment.export(mp3_buffer, format="mp3", bitrate="64k")
        mp3_data = mp3_buffer.getvalue()
        
        # Send to transcription service (Whisper, Google Speech, etc.)
        # ... your transcription code here ...
        
        return jsonify({
            'status': 'success',
            'message': 'Audio received and processed',
            'samples': len(samples),
            'duration_sec': len(samples) / sample_rate
        }), 200
        
    except Exception as e:
        print(f"Error: {e}")
        return jsonify({
            'status': 'error',
            'message': str(e)
        }), 400

if __name__ == '__main__':
    app.run(host='0.0.0.0', port=8080)
```

### Install Dependencies

```bash
pip install flask numpy pydub

# pydub requires ffmpeg
# Mac: brew install ffmpeg
# Linux: sudo apt install ffmpeg
# Windows: Download from ffmpeg.org
```

---

## Converting to MP3 - Super Easy!

### Method 1: Using pydub (Easiest)

```python
from pydub import AudioSegment
import numpy as np

# Get samples from JSON
samples = np.array(data['audio']['data'], dtype=np.int16)
sample_rate = data['audio']['sample_rate']

# Create audio segment
audio = AudioSegment(
    samples.tobytes(),
    frame_rate=sample_rate,
    sample_width=2,  # 16-bit
    channels=1       # Mono
)

# Save as MP3
audio.export("output.mp3", format="mp3", bitrate="64k")
```

**That's it! 5 lines of code!**

### Method 2: Using scipy + lameenc

```python
import numpy as np
from scipy.io import wavfile
import subprocess

# Get samples
samples = np.array(data['audio']['data'], dtype=np.int16)

# Save as WAV first
wavfile.write('temp.wav', 16000, samples)

# Convert to MP3 with ffmpeg
subprocess.run([
    'ffmpeg', '-i', 'temp.wav',
    '-acodec', 'libmp3lame',
    '-ab', '64k',
    'output.mp3'
])
```

### Method 3: Direct to Whisper (No MP3 needed!)

```python
import whisper
import numpy as np

# Load Whisper model (once)
model = whisper.load_model("base")

# Get samples from device
samples = np.array(data['audio']['data'], dtype=np.int16)

# Convert to float32 (-1.0 to 1.0 range)
audio_float = samples.astype(np.float32) / 32768.0

# Transcribe directly!
result = model.transcribe(
    audio_float,
    fp16=False,
    language="en"
)

text = result["text"]
print(f"Transcription: {text}")

# Save with GPS location
save_transcription(text, gps_data)
```

**Even easier - no MP3 conversion needed!**

---

## Updated Firmware Details

### Memory Usage

**Audio Buffer:**
- 480,000 samples × 2 bytes = 960 KB
- Stored in PSRAM (8 MB available)
- Only ~12% of PSRAM used

**Upload Stats:**
- **Frequency:** 1 upload every 30 seconds
- **Chunk size:** ~960 KB (30 seconds of audio)
- **Bandwidth:** ~32 KB/sec average (256 Kbps)
- **Latency:** 30 seconds (acceptable for transcription)

### Pin Configuration

All pins match hardware exactly (verified):

```python
PINS = {
    'MIC_ADC': 1,       # Microphone
    'GPS_TX': 15,       # To GNSS RX
    'GPS_RX': 16,       # From GNSS TX
    'I2C_SDA': 21,      # Fuel gauge
    'I2C_SCL': 47,      # Fuel gauge
    'LED_RED': 4,       # Status
    'LED_GREEN': 5,     # Status
    'LED_BLUE': 6,      # Status
    'BTN_RECORD': 2,    # Record control
}
```

---

## LED Status

| Color | Meaning |
|---|---|
| Green | Ready / Idle |
| Red | Recording (solid during 30s buffer) |
| Blue | Connecting to WiFi |
| Green flash | Upload successful |
| Red flash | Upload failed |

---

## Server Processing Pipeline

```
1. Receive JSON with 480,000 samples (30 seconds)
2. Convert to numpy array
3. Option A: Save as MP3 (5 lines of code with pydub)
4. Option B: Transcribe directly (Whisper doesn't need MP3)
5. Tag transcription with GPS coordinates
6. Store in database with battery metadata
7. Respond with success
```

**Processing time:** ~5-30 seconds depending on transcription model

---

## Example Complete Server

```python
from flask import Flask, request, jsonify
import numpy as np
from pydub import AudioSegment
import whisper
import datetime

app = Flask(__name__)

# Load Whisper once at startup
model = whisper.load_model("base")

@app.route('/api/audio', methods=['POST'])
def receive_audio():
    data = request.json
    
    # Extract data
    samples = np.array(data['audio']['data'], dtype=np.int16)
    sample_rate = data['audio']['sample_rate']
    device_id = data['device_id']
    timestamp = data['timestamp']
    
    # GPS and battery
    gps = data.get('gps')
    battery = data['battery']
    
    print(f"\n[{datetime.datetime.now()}] Received from {device_id}")
    print(f"  Audio: {len(samples)} samples ({len(samples)/sample_rate:.1f}s)")
    if gps:
        print(f"  GPS: {gps['latitude']:.6f}, {gps['longitude']:.6f}")
    print(f"  Battery: {battery['soc']:.1f}%")
    
    # Option 1: Save as MP3
    audio = AudioSegment(
        samples.tobytes(),
        frame_rate=sample_rate,
        sample_width=2,
        channels=1
    )
    mp3_file = f"recordings/{device_id}_{timestamp}.mp3"
    audio.export(mp3_file, format="mp3", bitrate="64k")
    print(f"  Saved: {mp3_file}")
    
    # Option 2: Transcribe
    audio_float = samples.astype(np.float32) / 32768.0
    result = model.transcribe(audio_float, fp16=False, language="en")
    text = result["text"]
    print(f"  Transcription: {text[:100]}...")
    
    # Save to database with GPS
    # save_to_db(device_id, text, gps, battery, timestamp)
    
    return jsonify({
        'status': 'success',
        'transcription': text,
        'mp3_file': mp3_file
    }), 200

if __name__ == '__main__':
    import os
    os.makedirs('recordings', exist_ok=True)
    app.run(host='0.0.0.0', port=8080)
```

**Dependencies:**
```bash
pip install flask numpy pydub openai-whisper
brew install ffmpeg  # or apt install ffmpeg
```

Run:
```bash
python server.py
# Server ready on port 8080
```

---

## Updated Specifications

### Audio Transmission

- **Buffer:** 30 seconds (480,000 samples)
- **Upload Frequency:** Once every 30 seconds
- **Payload Size:** ~960 KB per upload
- **Average Bandwidth:** ~32 KB/sec (256 Kbps)
- **Memory Used:** 960 KB (12% of 8MB PSRAM)

**Much better!**
- 15.6 uploads/sec → **1 upload/30sec** (467× reduction!)
- Still near real-time for transcription
- Much less network overhead
- More efficient for both device and server

### Server Processing

**Easy conversions available:**

| To Format | Library | Lines of Code |
|---|---|---|
| **MP3** | pydub | 5 lines ✅ |
| **WAV** | scipy.io.wavfile | 1 line ✅ |
| **FLAC** | pydub | 5 lines ✅ |
| **Transcription** | whisper | 3 lines ✅ |

**No complex encoding needed!** Raw PCM → MP3 conversion is trivial with pydub.

---

## File Structure

```
firmware/
├── config.py           Configuration (edit WiFi/server)
├── main.py             Main application
├── upload.sh           Upload script
├── FIRMWARE.md         This file
└── lib/
    ├── audio.py        ADC sampling (16kHz)
    ├── gps.py          NMEA parsing
    ├── battery.py      MAX17048 I2C
    ├── network.py      WiFi + HTTP
    └── hardware.py     LEDs + buttons
```

---

## Quick Reference

### Upload Firmware
```bash
cd firmware
./upload.sh /dev/ttyACM0
```

### Monitor Output
```bash
mpremote connect /dev/ttyACM0
```

### Debug Interactive
```bash
mpremote connect /dev/ttyACM0
>>> import main
>>> main.battery.get_voltage()
```

---

**For hardware details, see HARDWARE.md**  
**For programming/debugging, see QUICKSTART.md**

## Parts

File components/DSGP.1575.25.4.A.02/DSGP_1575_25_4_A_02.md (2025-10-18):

# TAOGLAS. 



## DSGP.1575.25.4.A.02

## Description:

GPS L1 / GALILEO E1 1575.42MHz 25*25*4mm Ceramic Patch SMD Antenna

## Features:

4.34 dBi Peak Gain for GPS/GALILEO Band

Dimensions: $25 \times 25 \times 4 \mathrm{~mm}$
SMD Direct Mount Ceramic Patch Antenna
TS16949 Approved
RoHS \& Reach Compliant1. Introduction ..... 3
2. Specifications ..... 4
3. Antenna Characteristics ..... 6
4. Radiation Patterns ..... 8
5. Mechanical Drawing ..... 10
6. Antenna Integration Guide ..... 11
7. Evaluation Board Mechanical Drawing ..... 16
8. PCB Footprint Recommendation ..... 17
9. Recommended Solder Reflow Profile ..... 19
10. Packaging ..... 20
Changelog ..... 22

Taoglas makes no warranties based on the accuracy or completeness of the contents of this document and reserves the right to make changes to specifications and product descriptions at any time without notice. Taoglas reserves all rights to this document and the information contained herein. Reproduction, use or disclosure to third parties without express permission is strictly prohibited.# 1. Introduction 



The DSGP.1575.25.4.A. 02 is a 25 mm ceramic GPS L1 / GALILEO E1 passive patch antenna. 25 mm square with a height of just 4 mm , this antenna is perfect for applications in telematics devices, vehicle tracking/fleet management systems, and navigation devices. Typical applicable industries include transportation, defense, marine, agriculture, and navigation.

The antenna has been tuned on a $50 * 50 \mathrm{~mm}$ ground plane, working at 1575.42 MHz with a 4.34 dBi gain. The antenna has a stable hemispherical radiation pattern. The ceramic patch is mounted via SMT process, ideal for high-volume, low-cost assembly. It is manufactured and tested in a TS16949 first tier automotive approved facility.

For further optimization to customer specific device environments, custom tuned patch antennas can be supplied, subject to NRE and MOQ. For more details please contact your regional Taoglas sales office.# 2. Specifications

|  GNSS Frequency Bands Covered |  |  |  |  |  |  |  | |
| --- | --- | --- | --- | --- | --- | --- | --- | --- |
|  GPS/QZSS | $\begin{gathered} \text { L1 } \ 1575.42 \mathrm{MHz} \end{gathered}$ | $\begin{gathered} \text { L2 } \ 1227.6 \mathrm{MHz} \end{gathered}$ | $\begin{gathered} \text { L5 } \ 1176.45 \mathrm{MHz} \end{gathered}$ | $\begin{gathered} \text { L6 } \ 1278.75 \mathrm{MHz} \end{gathered}$ |  |  |  | |
| | $\square$ | $\square$ | $\square$ | $\square$ |  |  |  | |
|  GLONASS | $\begin{gathered} \text { L5R } \ 1176.45 \mathrm{MHz} \end{gathered}$ | $\begin{gathered} \text { L3PT } \ 1201.5 \mathrm{MHz} \end{gathered}$ | $\begin{gathered} \text { L2PT } \ 1246 \mathrm{MHz} \end{gathered}$ | $\begin{gathered} \text { L1CR } \ 1575.42 \mathrm{MHz} \end{gathered}$ | $\begin{gathered} \text { L1PT } \ 1602 \mathrm{MHz} \end{gathered}$ |  |  | |
| | $\square$ | $\square$ | $\square$ | $\square$ | $\square$ |  |  | |
|  Galileo | $\begin{gathered} \text { E5a } \ 1176.45 \mathrm{MHz} \end{gathered}$ | $\begin{gathered} \text { E5b } \ 1201.5 \mathrm{MHz} \end{gathered}$ | $\begin{gathered} \text { E4 } \ 1215 \mathrm{MHz} \end{gathered}$ | $\begin{gathered} \text { E3 } \ 1256 \mathrm{MHz} \end{gathered}$ | $\begin{gathered} \text { E6 } \ 1278.75 \mathrm{MHz} \end{gathered}$ | $\begin{gathered} \text { E2 } \ 1561 \mathrm{MHz} \end{gathered}$ | $\begin{gathered} \text { L1 } \ 1575.42 \mathrm{MHz} \end{gathered}$ | |
| | $\square$ | $\square$ | $\square$ | $\square$ | $\square$ | $\square$ | $\square$ | $\square$  |
|  BeiDou | $\begin{gathered} \text { B1 } \ 1561 \mathrm{MHz} \end{gathered}$ | $\begin{gathered} \text { B2 } \ 1207.14 \mathrm{MHz} \end{gathered}$ | $\begin{gathered} \text { B3 } \ 1268.52 \mathrm{MHz} \end{gathered}$ |  |  |  |  | |
| | $\square$ | $\square$ | $\square$ |  |  |  |  | |
|  Compass | $\begin{gathered} \text { E5B(B2)/ E6(B3) } \ 1268.56 \mathrm{MHz} \end{gathered}$ | $\begin{gathered} \text { E2(B1) } \ 1561 \mathrm{MHz} \end{gathered}$ |  |  |  |  |  | |
| | $\square$ | $\square$ |  |  |  |  |  | |
|  SBAS | $\begin{gathered} \text { Omnistar } \ 1542.5 \mathrm{MHz} \end{gathered}$ | WAAS/EGN OS
1575.42 MHz |  |  |  |  |  |   |
| | $\square$ | $\square$ |  |  |  |  |  | ||  Electrical | |
| --- | --- |
|  Frequency (MHz) | 1575.42  |
|  VSWR (max.) | 2.0:1  |
|  Passive Antenna Efficiency (\%) | 85.13  |
|  Passive Antenna Gain at Zenith (dBi) | 4.34  |
|  Return Loss (dB) | $<-10$  |
|  Impedance | $50 \Omega$  |
|  Mechanical | |
|  Dimension | $25 \times 25 \times 4 \mathrm{~mm}$  |
|  Weight | 9.4 g  |
|  Environmental | |
|  Operation Temperature | $-40^{\circ} \mathrm{C}$ to $85^{\circ} \mathrm{C}$  |
|  Humidity | Non-condensing $65^{\circ} \mathrm{C} 95 \% \mathrm{RH}$  |
|  Moisture Sensitivity Level (MSL) | 3 (168 Hours)  |# 3. Antenna Characteristics 

### 3.1 Return Loss



### 3.2 Efficiency





### 3.4 Peak Gain



# 4. Radiation Patterns

## 4.1 Test Setup



*On Evaluation Board*

Taoglas Part number: DSGPD.25A

#### 4.2 1575.42MHz 3D and 2D Radiation Patterns









**Top View**

**Side View**

**Bottom View**# 6. Antenna Integration Guide 

# 6.1 Schematic Symbol and Pin Definition

The circuit symbol for the antenna is shown below. The antenna has 8 pins with all as functional.

|  Pin | Description  |
| --- | --- |
|  1 | RF Feed  |
|  $2,3,4,5,6,7,8$ | Ground  |

## TAOGLAS_DSGP.1575254A02 ANTI

# 6.2 Antenna Integration 

The antenna should be placed at the center of the ground plane with a length and width of 50 mm . Maintaining a square symmetric ground plane shape and symmetric environment around the antenna is critical to maintaining the excellent axial ratio and phase center performance shown in this datasheet.


Top Side w/ Solder Mask


Top Side w/o Solder Mask# 6.3 PCB Layout 

The footprint and clearance on the PCB must comply with the antenna specification. The PCB layout shown in the diagram below demonstrates the antenna footprint.


Topside


Bottom Side





**6.4 Evaluation Board**

Topside

Bottom Side# 7. Evaluation Board Mechanical Drawing 



Notes

1. Silver area
2. Solder mask
3. Solder Area

|  | Name | P/N | Material | Finish | $\square$ |
| :--: | :--: | :--: | :--: | :--: | :--: |
| 1 | PCB 5MA0F1 5T | 200411600007A | Brass | Au Plated | 1 |
| 2 | DSGP 1575.25.4.4.02 Antenna | 001514L050007A | Ceramic | Clear | 1 |
| 3 | PCB (50x50x1mm) | 1002130000007A | PPA 1.0t | Black | 1 |# 8. PCB Footprint Recommendation 

# Top Solder Mask 

Pads 1, 2, 3, 4, 5, 6, 7 and 9 are the same size,
This drawing is a negative of solder mask. Black regions are anti-mask.


## Composite Diagram



NOTE:

1. Ag Plated area
2. Solder Mask area
3. Copper area
4. Paste area
5. Copper Keepout Area
6. Copper keepout should extend through all PCB layers.
7. Any vias in pads should be either filled or tented to prevent solder from wicking away from the pad during reflow.
8. The dimension tolerances should follow standard PCB manufacturing guidelines# 9. Recommended Solder Reflow Profile 

The DSGP.1575.25.4.A. 02 can be assembled by following the recommended soldering temperatures are as follows:

Temp $\left({ }^{\circ} \mathbf{C}\right)$

*Temperatures listed within a tolerance of $+/-10^{\circ} \mathrm{C}$
Smaller components are typically mounted on the first pass, however, we do advise mounting the DSGP.1575.25.4.A. 02 when placing larger components on the board during subsequent reflows.# 10. Packaging 

200 pc DSGP1575.25.4.A. 02 per reel
Dimensions - $\varnothing 330 * 55 \mathrm{~mm}$
Weight -2330 g
# TAOGLAS. 

1 pc reel in small in Anti-static Bag Dimensions - 340*350*70mm Weight - 2.63Kg


4 Reels / 800 pcs in one carton Carton Dimensions - 370*360*305mm Weight - 11.3Kg


Pallet Dimensions 1200*1000*1420mm
24 Cartons per Pallet
6 Cartons per layer
4 Layers# TAOGLAS.

## Changelog for the datasheet

SPE-17-8-036- DSGF.1575.25.4.A.02

|  Revision: C (Current Version) | |
| --- | --- |
|  Date: | $2024-10-24$  |
|  Changes: | Updated Solder Reflow Profile.  |
|  Changes Made by: | Cesar Sousa  |

## Previous Revisions

|  Revision: B | |
| --- | --- |
|  Date: | $2023-03-24$  |
|  Changes: | Antenna Integration Guide Added  |
|  Changes Made by: | Cesar Sousa  |
|  Revision: A (Original First Release) | |
|  Date: | $2017-05-22$  |
|  Notes: | |
|  Author: | Jack Conroy  |



www.taoglas.com

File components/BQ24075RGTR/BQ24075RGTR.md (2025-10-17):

# BQ2407x Standalone 1-Cell 1.5-A Linear Battery Chargers with Power Path 

## 1 Features

- Fully compliant USB charger
- Selectable 100-mA and 500-mA maximum input current
- 100-mA Maximum current limit ensures compliance to USB-IF standard
- Input-based dynamic power management ( $\mathrm{V}_{\mathrm{IN}}$ DPM) for protection against poor USB sources
- Functional Safety-Capable (BQ24074)
- Documentation available to aid functional safety system design
- 28-V Input rating with overvoltage protection
- Integrated dynamic power path management (DPPM) function simultaneously and independently powers the system and charges the battery
- Supports up to 1.5-A charge current with current monitoring output (ISET)
- Programmable input current limit up to 1.5 A for wall adapters
- System output tracks battery voltage (BQ24072)
- Programmable termination current (BQ24074)
- Battery disconnect function with SYSOFF input (BQ24075, BQ24079)
- Programmable pre-charge and fast-charge safety timers
- Reverse current, short-circuit and thermal protection
- NTC thermistor input
- Proprietary start-up sequence limits inrush current
- Status indication - charging/done, power good
- Safety-Related Certification:
- IEC 62368-1 Certification (BQ24072)

## 2 Applications

- TWS Charging case and headphones
- Gaming accessory
- Video doorbells, IP network cameras
- Asset tracking and fleet management
- Portable medical devices

## 3 Description

The BQ2407x series of devices are integrated Li-lon linear chargers and system power path management devices targeted at space-limited portable applications. The devices operate from either a USB port or an AC adapter and support charge currents up to 1.5 A . The input voltage range with input overvoltage protection supports unregulated adapters. The USB input current limit accuracy and start up sequence allow the BQ2407x to meet USB-

IF inrush current specifications. Additionally, the input dynamic power management ( $\mathrm{V}_{\mathrm{IN}}$-DPM) prevents the charger from crashing incorrectly configured USB sources.

The BQ2407x features dynamic power path management (DPPM) that powers the system while simultaneously and independently charging the battery. The DPPM circuit reduces the charge current when the input current limit causes the system output to fall to the DPPM threshold; thus, supplying the system load at all times while monitoring the charge current separately. This feature reduces the number of charge and discharge cycles on the battery, allows for proper charge termination and enables the system to run with a defective or absent battery pack.

Device Information

| PART NUMBER ${ }^{(1)}$ | PACKAGE | BODY SIZE (NOM) |
| :-- | :-- | :-- |
| BQ24072 |  |  |
| BQ24073 | VQFN (16) | $3.00 \mathrm{~mm} \times 3.00 \mathrm{~mm}$ |
| BQ24074 |  |  |
| BQ24075 |  |  |
| BQ24079 |  |  |

(1) For all available packages, see the orderable addendum at the end of the data sheet.


Typical Application Circuit# Table of Contents 

1 Features ..... 1
2 Applications ..... 1
3 Description ..... 1
4 Revision History ..... 2
5 Description (continued) ..... 5
6 Device Comparison Table ..... 6
7 Pin Configuration and Functions ..... 7
8 Specifications ..... 10
8.1 Absolute Maximum Ratings ${ }^{(1)}$ ..... 10
8.2 ESD Ratings ..... 10
8.3 Recommended Operating Conditions ..... 10
8.4 Thermal Information ..... 11
8.5 Electrical Characteristics ..... 12
8.6 Typical Characteristics ..... 14
9 Detailed Description ..... 17
9.1 Overview ..... 17
9.2 Functional Block Diagram ..... 18
9.3 Feature Description ..... 19
9.4 Device Functional Modes ..... 31
10 Application and Implementation ..... 33
10.1 Application Information ..... 33
10.2 Typical Application ..... 33
10.3 System Examples ..... 38
11 Power Supply Recommendations ..... 39
12 Layout ..... 40
12.1 Layout Guidelines ..... 40
12.2 Layout Example ..... 41
12.3 Thermal Considerations ..... 42
13 Device and Documentation Support ..... 43
13.1 Device Support ..... 43
13.2 Receiving Notification of Documentation Updates ..... 43
13.3 Support Resources ..... 43
13.4 Trademarks ..... 43
13.5 Electrostatic Discharge Caution ..... 43
13.6 Glossary ..... 43
14 Mechanical, Packaging, and Orderable Information ..... 43

## 4 Revision History

NOTE: Page numbers for previous revisions may differ from page numbers in the current version.
Changes from Revision M (August 2019) to Revision N (October 2021) Page

- Added Functional Safety-Capable (BQ24074) to Features ..... 1
- Added Safety-Related Certification: IEC 62368-1 Certification (BQ24072) to Features ..... 1
- Changed Applications ..... 1
- Changed BQ24079T information and package in Section 6 ..... 6
- Added $\mathrm{I}_{\text {BAT(PDWN) }}$ TYP value ..... 12
- Added I $_{\text {IN }}$ TYP values ..... 12
- Added $\mathrm{I}_{\mathrm{CC}}$ TYP value ..... 12
Changes from Revision L (June 2018) to Revision M (August 2019) Page
- Changed the document title ..... 1
- Changed the Device Comparison Table ..... 6
- Deleted the Dissipation Ratings table ..... 11
- Changed $\mathrm{V}_{\text {IN-LOW }}$ To $\mathrm{V}_{\text {IN-DPM }}$ in the Functional Block Diagram ..... 18
- Changed text From: "the DPPM loop or the $\mathrm{V}_{\text {IN-(LOW) }}$ loop." To: "the DPPM loop or the $\mathrm{V}_{\text {IN-DPM }}$ loop." in the Battery Charging secton ..... 24
- Chganged text From: " input voltage has fallen to $\mathrm{V}_{\text {IN(LOW) }}$ " To: "input voltage has fallen to $\mathrm{V}_{\text {IN-DPM }}$ " in the Dynamic Charge Timers (TMR Input) scrtion ..... 27
- Changed Equation 11 ..... 42
Changes from Revision K (March 2015) to Revision L (June 2018) Page
- Deleted MARKINGS from the Device Comparison Table ..... 6
- Added the RGT0016B and RGT0016C package information to the Device Comparison Table ..... 6
- Changed the Pinout images and descriptions ..... 7
- Change description of the CE pin From: "Connect CE to a high logic level to place the battery charger in standby mode. In standby mode, ..." To ""Connect CE to a high logic level to disable battery charging. OUT is active and battery supplement mode is still available." ..... 7
- "Changed text in the third paragraph of the Power On section From: When $\mathrm{V}_{\text {OUT }}$ is above $\mathrm{V}_{\mathrm{SC}}$, ..." To: "When $\mathrm{V}_{\text {OUT }}$ is above $\mathrm{V}_{\mathrm{O}(\mathrm{SC} 1) \ldots}$ ..... 19- Changed text From: "The valid resistor range is $590 \Omega$ to $5.9 \mathrm{k} \Omega$." To: "The valid resistor range is $590 \Omega$ to 8.9 $\mathrm{k} \Omega$." in the Battery Charging section. ..... 24
- Changed From: $\mathrm{V}_{\mathrm{IN}(\mathrm{DT})}$ To: $\mathrm{V}_{\mathrm{BAT}}+\mathrm{V}_{\mathrm{IN}(\mathrm{DT})}$ in Table 9-1 ..... 28
- Changed $\mathrm{I}_{\mathrm{NTC}}$ To: $\mathrm{I}_{\mathrm{TS}}$ in Figure 9-9 ..... 29
Changes from Revision J (January 2015) to Revision K (March 2015) ..... Page
- Deleted package type code from Device Comparison Table. See the POA at the end of the data sheet. ..... 6
- Changed $\mathrm{I}_{\mathrm{CHG}}$ Battery fast charge current range MIN specification from "150 mA " to "100 mA" ..... 12
Changes from Revision I (January 2014) to Revision J (January 2015) ..... Page
- Added ESD Ratings table, Feature Description section, Device Functional Modes, Application and Implementation section, Power Supply Recommendations section, Layout section, Device and Documentation Support section, and Mechanical, Packaging, and Orderable Information section ..... 1
Changes from Revision H (December 2013) to Revision I (January 2014) ..... Page
- Changed resistor value from " $3 \mathrm{k} \Omega$ " to " $8.9 \mathrm{k} \Omega$ " in the Pin Functions table ISET Description paragraph. ..... 7
- Changed $\mathrm{R}_{\text {ISET }}$ spec MAX value from " 3000 " to " 8900 " in the Recommended Operating Conditions table. ..... 10
- Changed resistor value from " $3 \mathrm{k} \Omega$ " to " $5.9 \mathrm{k} \Omega$ " in the Battery Charging section paragraph. ..... 24
Changes from Revision G (July 2011) to Revision H (December 2013) ..... Page
- Changed $\mathrm{I}_{\mathrm{CHG}}$ Battery fast charge current range MIN specification from " 300 mA " to " 150 mA ". ..... 12
Changes from Revision F (September 2010) to Revision G (July 2011) ..... Page
- Added ESD human body model specification to Abs Maximum Ratings table. ..... 10
Changes from Revision E (August 2010) to Revision F (September 2010) ..... Page
- Changed $10 \times 45 \mathrm{~s} / \mathrm{k} \Omega$ to $10 \times 48 \mathrm{~s} / \mathrm{k} \Omega$ under section Program 6.25 hour. (TMR) ..... 34
Changes from Revision D (June 2009) to Revision E (August 2010) ..... Page
- Changed globally RT1 and RT2 to Rs and Rp. ..... 29
- Added equations 2 and 3 plus explanations and table. ..... 29
Changes from Revision C (March 2009) to Revision D (June 2009) ..... Page
- Added Device number BQ24079 ..... 1
Changes from Revision B (January 2009) to Revision C (March 2009) ..... Page
- Changed Maximum input current factor values. ..... 12
Changes from Revision A (December 2008) to Revision B (January 2009) ..... Page
- Changed $\mathrm{V}_{\text {BAT(REG) }}$ max value From 4.24 V To: 4.23 V ..... 12Changes from Revision * (September 2008) to Revision A (December 2008) ..... Page

- Changed device Features ..... 1
- Changed Description ..... 1
- Changed Typical Application Circuit ..... 1
- Changed description of $\overline{\mathrm{CHG}}$ pin ..... 7
- Changed SYSOFF Description ..... 7
- Added Figure 10-5 through Figure 8-1 ..... 14
- Changed DETAILED FUNCTIONAL DESCRIPTION section ..... 17
- Changed the Functional Block Diagram ..... 18
- Changed text in section - STATUS INDICATORS ( PGOOD, CHG) ..... 28
- Changed Table - $\overline{\text { CHG }}$ STATUS INDICATOR ..... 28
- Changed Equation 8 and Equation 9 ..... 29
- Changed APPLICATION CIRCUITS section ..... 33
- Added Using BQ24075 to Disconnect the Battery from the System, Figure 10-13 ..... 38
- Changed section - Half-Wave Adaptors ..... 39# 5 Description (continued) 

Additionally, the regulated system input enables instant system turn-on when plugged in even with a totally discharged battery. The power path management architecture also lets the battery supplement the system current requirements when the adapter cannot deliver the peak system currents, thus enabling the use of a smaller adapter.

The battery is charged in three phases: conditioning, constant current, and constant voltage. In all charge phases, an internal control loop monitors the IC junction temperature and reduces the charge current if the internal temperature threshold is exceeded. The charger power stage and charge current sense functions are fully integrated. The charger function has high accuracy current and voltage regulation loops, charge status display, and charge termination. The input current limit and charge current are programmable using external resistors.# 6 Device Comparison Table 

| PART NUMBER ${ }^{(1)(2)}$ | $\mathrm{V}_{\text {OVP }}$ | $\mathrm{V}_{\text {BAT(REG) }}$ | $\mathrm{V}_{\text {OUT(REG) }}$ | $\mathrm{V}_{\text {OPPM }}$ | TS METHOD | OPTIONAL FUNCTION | PACKAGE |
| :--: | :--: | :--: | :--: | :--: | :--: | :--: | :--: |
| BQ24072 | 6.6 V | 4.2 V | $\mathrm{V}_{\text {BAT }}+225 \mathrm{mV}$ | $\mathrm{V}_{\text {O(REG) }}-100 \mathrm{mV}$ | Current Based | TD | RGT0016C |
| BQ24073 | 6.6 V | 4.2 V | 4.4 V | $\mathrm{V}_{\text {O(REG) }}-100 \mathrm{mV}$ |  | TD |  |
| BQ24074 | 10.5 V | 4.2 V | 4.4 V | $\mathrm{V}_{\text {O(REG) }}-100 \mathrm{mV}$ |  | ITERM |  |
| BQ24075 | 6.6 V | 4.2 V | 5.5 V | 4.3 V |  | SYSOFF |  |
| BQ24076 | 6.6 V | 4.4 V | $\mathrm{V}_{\text {BAT }}+225 \mathrm{mV}$ | $\mathrm{V}_{\text {O(REG) }}-100 \mathrm{mV}$ |  | SYSOFF |  |
| BQ24078 | 6.6 V | 4.35 V | $\mathrm{V}_{\text {BAT }}+225 \mathrm{mV}$ | $\mathrm{V}_{\text {O(REG) }}-100 \mathrm{mV}$ |  | SYSOFF |  |
| BQ24079 | 6.6 V | 4.1 V | 5.5 V | 4.3 V |  | SYSOFF |  |
| BQ24072T | 6.6 V | 4.2 V | $\mathrm{V}_{\text {BAT }}+225 \mathrm{mV}$ | $\mathrm{V}_{\text {O(REG) }}-100 \mathrm{mV}$ | Voltage Based | TD |  |
| BQ24075T | 6.6 V | 4.2 V | 5.5 V | 4.3 V |  | SYSOFF |  |
| BQ24079T | 6.6 V | 4.1 V | 5.5 V | 4.3 V |  | SYSOFF |  |

(1) For all available packages, see the orderable addendum at the end of the data sheet
(2) This product is RoHS compatible, including a lead concentration that does not exceed $0.1 \%$ of total product weight, and is suitable for use in specified lead-free soldering processes. In addition, this product uses package materials that do not contain halogens, including bromine $(\mathrm{Br})$ or antimony $(\mathrm{Sb})$ above $0.1 \%$ of total product weight.# 7 Pin Configuration and Functions 



Figure 7-1. BQ24072, BQ24073 RGT0016B Package 16 Pins Top View


Figure 7-2. BQ24074 RGT0016B Package 16 Pins Top View

Figure 7-3. BQ24075 RGT0016C Package, BQ24079 RGT0016B Package 16 Pins Top View
Table 7-1. Pin Functions

| PIN |  |  |  |  | I/O | DESCRIPTION |
| :--: | :--: | :--: | :--: | :--: | :--: | :--: |
| NAME | '72, '73 | '74 | '75, '79 |  |  |  |
| BAT | 2,3 | 2,3 | 2,3 | I/O | Charger Power Stage Output and Battery Voltage Sense Input. Connect BAT to the positive terminal of the battery. Bypass BAT to VSS with a $4.7-\mu \mathrm{F}$ to $47-\mu \mathrm{F}$ ceramic capacitor. |  |
| CE | 4 | 4 | 4 | I | Charge Enable Active-Low Input. Connect CE to a high logic level to disable battery charging. OUT is active and battery supplement mode is still available. Connect CE to a low logic level to enable the battery charger. CE is internally pulled down with approximately $285 \mathrm{k} \Omega$. Do not leave CE unconnected to ensure proper operation. |  |
| CHG | 9 | 9 | 9 | 0 | Open-Drain Charging Status Indication Output. CHG pulls to VSS when the battery is charging. CHG is high impedance when charging is complete and when charger is disabled. Connect CHG to the desired logic voltage rail using a $1 \mathrm{k} \Omega-100 \mathrm{k} \Omega$ resistor, or use with an LED for visual indication. |  |
| EN1 | 6 | 6 | 6 | I | Input Current Limit Configuration Inputs. Use EN1 and EN2 control the maximum input current and enable USB compliance. See Table 7-2 for the description of the operation states. EN1 and EN2 are internally pulled down with $+285 \mathrm{k} \Omega$. Do not leave EN1 or EN2 unconnected to ensure proper operation. |  |
| EN2 | 5 | 5 | 5 | I |  | Adjustable Current Limit Programming Input. Connect a $1100-\Omega$ to $8-\mathrm{k} \Omega$ resistor from ILIM to VSS to program the maximum input current (EN2=1, EN1=0). The input current includes the system load and the battery charge current. Leaving ILIM unconnected disables all charging. |
| ILIM | 12 | 12 | 12 | I |  | Input Power Connection. Connect IN to the external DC supply (AC adapter or USB port). The input operating range is 4.35 V to 6.6 V (BQ24072, BQ24073, BQ24075, and BQ24079) or 4.35 V to 10.5 V (bq24074). The input can accept voltages up to 26 V without damage but operation is suspended. Connect bypass capacitor $1 \mu \mathrm{~F}$ to $10 \mu \mathrm{~F}$ to VSS. |
| IN | 13 | 13 | 13 | I |  | Fast Charge Current Programming Input. Connect a $590-\Omega$ to $8.9-\mathrm{k} \Omega$ resistor from ISET to VSS to program the fast charge current level. Charging is disabled if ISET is left unconnected. While charging, the voltage at ISET reflects the actual charging current and can be used to monitor charge current. See Section 9.3.5.1 for more details. |
| ISET | 16 | 16 | 16 | I/O |  | Termination Current Programming Input. Connect a $0-\Omega$ to $15-\mathrm{k} \Omega$ resistor from ITERM to VSS to program the termination current. Leave ITERM unconnected to set the termination current to the default 10\% termination threshold. |
| ITERM | - | 15 | - | I |  | System Supply Output. OUT provides a regulated output when the input is below the OVP threshold and above the regulation voltage. When the input is out of the operation range, OUT is connected to $\mathrm{V}_{\mathrm{BAT}}$ except when SYSOFF is high (BQ24075 and BQ24079 only). Connect OUT to the system load. Bypass OUT to VSS with a $4.7-\mu \mathrm{F}$ to $47-\mu \mathrm{F}$ ceramic capacitor. |
| OUT | 10,11 | 10, 11 | 10, 11 | 0 |  | Open-drain Power Good Status Indication Output. PGOOD pulls to VSS when a valid input source is detected. PGOOD is high-impedance when the input power is not within specified limits. Connect PGOOD to the desired logic voltage rail using a $1-\mathrm{k} \Omega$ to $100-\mathrm{k} \Omega$ resistor, or use with an LED for visual indication. |
| PGOOD | 7 | 7 | 7 | 0 |  | System Enable Input. Connect SYSOFF high to turn off the FET connecting the battery to the system output. When an adapter is connected, charging is also disabled. Connect SYSOFF low for normal operation. SYSOFF is internally pulled up to $\mathrm{V}_{\mathrm{BAT}}$ through a large resistor (approximately $5 \mathrm{M} \Omega$ ). Do not leave SYSOFF unconnected to ensure proper operation. |Table 7-1. Pin Functions (continued)

|  PIN |  |  |  |  | DESCRIPTION  |
| --- | --- | --- | --- | --- | --- |
|  NAME | '72, '73 | '74 | '75, '79 |  | |
|  TD | 15 | - | - | I | Termination Disable Input. Connect TD high to disable charger termination. Connect TD to VSS to enable charger termination. TD is checked during startup only and cannot be changed during operation. See the TD section in this datasheet for a description of the behavior when termination is disabled. TD is internally pulled down to VSS with approximately $285 \mathrm{k} \Omega$. Do not leave TD unconnected to ensure proper operation.  |
|  Thermal Pad | - | - | - | - | There is an internal electrical connection between the exposed thermal pad and the VSS pin of the device. The thermal pad must be connected to the same potential as the VSS pin on the printed circuit board. Do not use the thermal pad as the primary ground input for the device. VSS pin must be connected to ground at all times.  |
|  TMR | 14 | 14 | 14 | I | Timer Programming Input. TMR controls the pre-charge and fast-charge safety timers. Connect TMR to VSS to disable all safety timers. Connect a $18-\mathrm{k} \Omega$ to $72-\mathrm{k} \Omega$ resistor between TMR and VSS to program the timers a desired length. Leave TMR unconnected to set the timers to the default values.  |
|  TS | 1 | 1 | 1 | I | External NTC Thermistor Input. Connect the TS input to the NTC thermistor in the battery pack. TS monitors a $10 \mathrm{k} \Omega$ NTC thermistor. For applications that do not use the TS function, connect a $10-\mathrm{k} \Omega$ fixed resistor from TS to VSS to maintain a valid voltage level on TS.  |
|  VSS | 8 | 8 | 8 | - | Ground. Connect to the thermal pad and to the ground rail of the circuit.  |

Table 7-2. EN1/EN2 Settings

| EN2 | EN1 | MAXIMUM INPUT CURRENT INTO IN PIN |
| :--: | :--: | :-- |
| 0 | 0 | 100 mA . USB100 mode |
| 0 | 1 | 500 mA . USB500 mode |
| 1 | 0 | Set by an external resistor from ILIM to VSS |
| 1 | 1 | Standby (USB suspend mode) |# 8 Specifications 

### 8.1 Absolute Maximum Ratings ${ }^{(1)}$

over the $0^{\circ} \mathrm{C}$ to $125^{\circ} \mathrm{C}$ operating free-air temperature range (unless otherwise noted)

|  |  |  | MIN | MAX | UNIT |
| :--: | :--: | :--: | :--: | :--: | :--: |
| $V_{i}$ | Input Voltage | IN (with respect to VSS) | $-0.3$ | 28 | V |
|  |  | BAT (with respect to VSS) | $-0.3$ | 5 | V |
|  |  | OUT, EN1, EN2, CE, TS, ISET, PGOOD, CHG, ILIM, TMR, ITERM, SYSOFF, TD (with respect to VSS) | $-0.3$ | 7 | V |
| $I_{i}$ | Input Current | IN |  | 1.6 | A |
| $I_{0}$ | Output Current (Continuous) | OUT |  | 5 | A |
|  |  | BAT (Discharge mode) |  | 5 | A |
|  |  | BAT (Charging mode) |  | $1.5^{(2)}$ | A |
|  | Output Sink Current | CHG, PGOOD |  | 15 | mA |
| $T_{J}$ | Junction temperature |  | $-40$ | 150 | ${ }^{\circ} \mathrm{C}$ |
| $T_{\text {stg }}$ | Storage temperature |  | $-65$ | 150 | ${ }^{\circ} \mathrm{C}$ |

(1) Stresses beyond those listed under Absolute Maximum Ratings may cause permanent damage to the device. These are stress ratings only, and functional operation of the device at these or any other conditions beyond those indicated under Section 8.3 is not implied. Exposure to absolute-maximum-rated conditions for extended periods may affect device reliability. All voltage values are with respect to the network ground terminal unless otherwise noted.
(2) The IC operational charging life is reduced to 20,000 hours, when charging at 1.5 A and $125^{\circ} \mathrm{C}$. The thermal regulation feature reduces charge current if the IC's junction temperature reaches $125^{\circ} \mathrm{C}$; thus without a good thermal design the maximum programmed charge current may not be reached.

### 8.2 ESD Ratings

|  |  |  | VALUE | UNIT |
| :--: | :--: | :--: | :--: | :--: |
| $V_{i E S D}$ | Electrostatic discharge | Human body model (HBM), per ANSI/ESDA/JEDEC JS-001 ${ }^{(1)}$ | $\pm 2000$ | V |
|  |  | Charged-device model (CDM), per JEDEC specification JESD22- <br> C101(2) | $\pm 500$ |  |

(1) JEDEC document JEP155 states that 500-V HBM allows safe manufacturing with a standard ESD control process.
(2) JEDEC document JEP157 states that 250-V CDM allows safe manufacturing with a standard ESD control process.
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

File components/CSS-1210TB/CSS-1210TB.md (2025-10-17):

# COMPACT SLIDE SWITCHES 

## RoHS compliant



## FEATURES

- Low-profile of 2 mm
- Self-return type available
- RoHS compliant
- Resin material is UL Recognized 94V-0

## APPLICATIONS

- Mobile stereo $\cdot$ LCD TV $\cdot$ Camcorder

## PART NUMBER DESIGNATION

# LIST OF PART NUMBERS 

| No. of contacts | Setting position | Self-return function | Shape of terminal | Form of packaging | Part number | Packaging quantity |
| :--: | :--: | :--: | :--: | :--: | :--: | :--: |
| 2 | Side setting | No function | B (Gull wing) | Taping | CSS-1210TB | 1,900 pcs./reel |
|  |  |  | C (Through hole pins) | Magazine | CSS-1210MC | 53 pcs./stick |
|  |  | Single | B (Gull wing) | Taping | CSS-1211TB | 1,900 pcs./reel |
|  |  |  | C (Through hole pins) | Magazine | CSS-1211MC | 53 pcs./stick |
| 3 | Side setting | No function | B (Gull wing) | Taping | CSS-1310TB | 1,900 pcs./reel |
|  |  |  | C (Through hole pins) | Magazine | CSS-1310MC | 38 pcs./stick |
|  |  | Single | B (Gull wing) | Taping | CSS-1311TB | 1,900 pcs./reel |
|  |  |  | C (Through hole pins) | Magazine | CSS-1311MC | 38 pcs./stick |
|  |  | Double | B (Gull wing) | Taping | CSS-1312TB | 1,900 pcs./reel |
|  |  |  | C (Through hole pins) | Magazine | CSS-1312MC | 38 pcs./stick |
|  | Top setting | No function | C (Through hole pins) | Magazine | CSS-1300MC | 38 pcs./stick |
|  |  | Double | C (Through hole pins) | Magazine | CSS-1302MC | 38 pcs./stick |

## STANDARD SPECIFICATIONS

| Operating temp. range | $-20 \sim 70^{\circ} \mathrm{C}$ |
| :-- | :-- |
| Storage temp. range | $-40 \sim 85^{\circ} \mathrm{C}$ |
| Sealing | Non- Washable |
| Net weight | Approx. 0.11 g (CSS-12), Approx. 0.15 g (CSS-13) |

## MECHANICAL CHARACTERISTICS

| No. of positions | 2,3 |
| :-- | :-- |
| Stroke | 2 mm |
| Operating force | $1 \sim 3.5 \mathrm{~N}\{0.1 \sim 0.36 \mathrm{kgf}\}$ |
| Stop strength | $10 \mathrm{~N}\{1.02 \mathrm{kgf}\} 15 \mathrm{~s}$ |
| Solderability | $245 \pm 3{ }^{\circ} \mathrm{C} \quad 2 \sim 3 \mathrm{~s}$ |
|  | $\mathrm{Sn}-3 \mathrm{Ag}-0.5 \mathrm{Cu}$ |
| Soldering heat | Reflow $: 250 \sim 255^{\circ} \mathrm{C}$ (Peak temperature) |
|  | (Please refer to the profile below) |
|  | Manual soldering $: 350 \pm 10^{\circ} \mathrm{C}, 3 \sim 4 \mathrm{~s}$ |
| Shear (Adhesion) | $5 \mathrm{~N}\{0.5 \mathrm{kgf}\} 10 \mathrm{~s}$ |
| Substrate bending | Width 90 mm , bend $3 \mathrm{~mm}, 5 \mathrm{~s}, 1$ time |
| Pull-off strength | $5 \mathrm{~N}\{0.5 \mathrm{kgf}\} 10 \mathrm{~s}$ |

## ELECTRICAL CHARACTERISTICS

| Contact rating | Non-switching: DC50 V, 100 mA Switching: DC12 V, 100 mA Minimum : DC20 mV, 1 µA |
| :--: | :--: |
| Contact timing | Non-shorting |
| Contact resistance | 70 m $\Omega$ maximum |
| Insulation resistance | 100 M $\Omega$ minimum (DC500 V) |
| Dielectric strength | AC500 V, 60 s |

## ENVIRONMENTAL CHARACTERISTICS

| Vibration | $\begin{gathered} 1.5 \mathrm{~mm}, 98 \mathrm{~m} / \mathrm{s}^{2} \\ 10-500-10 \mathrm{~Hz} \\ \text { Amplitude } 1.5 \mathrm{~mm} \text { or Acceleration } 98 \mathrm{~m} / \mathrm{s}^{2} \\ 10-500-10 \mathrm{~Hz}, 3 \text { directions for } 10 \text { cycles each } \end{gathered}$ |
| :--: | :--: |
| Shock | $490 \mathrm{~m} / \mathrm{s}^{2}, 11 \mathrm{~ms}, 6$ directions for 3 times each |
| Load life | Continuous load 10000 cycles, DC12 $\times 0.5 \mathrm{~V}, 100 \times 10 \mathrm{~mA}$ |
| Humidity | $40^{\circ} \mathrm{C}, 90 \sim 95 \%, 240 \mathrm{~h}$ <br> $40^{\circ} \mathrm{C}$, Relative humidity $90 \sim 95 \%, 240 \mathrm{~h}$, No load |
| High temp. exposure | $85^{\circ} \mathrm{C}, 96 \mathrm{~h}$, No load |
| Low temp. exposure | $-40^{\circ} \mathrm{C}, 96 \mathrm{~h}$, No load |
| Thermal shock | $-40(0.5 \mathrm{~h}) \sim 85^{\circ} \mathrm{C}(0.5 \mathrm{~h}), 5$ cycles |

〈Reflow profile for soldering heat evaluation〉


Reflow : two times maximum## OUTLINE DIMENSIONS

## C55-1210B



- C55-1310B

- C55-1312B


Unless otherwise specified, tolerance : $\pm 0.2$ (Unit : mm )

## C55-1211B



C55-1311B


C55-1210C
OUTLINE DIMENSIONS

- CSS-1211C

- CSS-1311C

- CSS-1300C


Unless otherwise specified, tolerance : $\pm 0.2$ (Unit : mm)

# - CSS-1310C 



CSS-1312C


## - CSS-1302C

# CSS <br> COMPACT SLIDE SWITCHES 

## RECOMMENDED P.C.B. PAD OUTLINE DIMENSIONS

CSS-121:B


## PACKAGING SPECIFICATIONS

Taping version is packaged in 1900 pcs. par reel.
Taping version is boxed with 1 reel ( 1900 pcs.).
Maximum number of consecutive missing pieces $=2$.
Leader length and reel dimension are shown in the diagrams below.

## - CSS-121:TB



Reel dimensions
(Unit: mm)


Reel shape and dimensions

| Part number | A | W. | W. | N |  | Part number | Quantity / Stick |
| :--: | :--: | :--: | :--: | :--: | :--: | :--: | :--: |
| 121:TB | $\varnothing 330 \times 2$ | $17.4 \pm 1$ | $21.4 \pm 1$ | $\varnothing 80 \pm 1$ |  | 12:1 | 53 |
| 131:TB | $\varnothing 330 \times 2$ | $25.4 \pm 1$ | $29.4 \pm 1$ | $\varnothing 80 \pm 1$ |  | 13:1 | 38 |

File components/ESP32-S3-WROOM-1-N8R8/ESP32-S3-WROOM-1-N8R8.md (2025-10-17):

# ESP32-S3-WROOM-1 ESP32-S3-WROOM-1U

## Datasheet Version 1.6

2.4 GHz Wi-Fi (802.11b/g/n) and Bluetooth® 5 module

Built around ESP32-S3 series of SoCs, Xtensa® dual-core 32-bit LX7 microprocessor

Flash up to 16 MB, PSRAM up to 16 MB

Up to 36 GPIOs, rich set of peripherals

On-board PCB antenna or external antenna connector







ESP32-S3-WROOM-1

ESP32-S3-WROOM-1U

# 1 Module Overview 

## Note:

Check the link or the QR code to make sure that you use the latest version of this document: https://www.espressif.com/documentation/esp32-s3-wroom-1_wroom-1u_datasheet_en.pdf

### 1.1 Features

## CPU and On-Chip Memory

- ESP32-S3 series of SoCs embedded, Xtensa ${ }^{\circledR}$ dual-core 32-bit LX7 microprocessor (with single precision FPU), up to 240 MHz
- 384 KB ROM
- 512 KB SRAM
- 16 KB SRAM in RTC
- Up to 16 MB PSRAM

## Wi-Fi

- $802.11 \mathrm{~b} / \mathrm{g} / \mathrm{n}$
- Bit rate: 802.11n up to 150 Mbps
- A-MPDU and A-MSDU aggregation
- $0.4 \mu \mathrm{~s}$ guard interval support
- Center frequency range of operating channel: $2412 \sim 2484 \mathrm{MHz}$

## Bluetooth

- Bluetooth LE: Bluetooth 5, Bluetooth mesh
- Speed: 125 Kbps, 500 Kbps, 1 Mbps, 2 Mbps
- Advertising extensions
- Multiple advertisement sets
- Channel selection algorithm \#2
- Internal co-existence mechanism between Wi-Fi and Bluetooth to share the same antenna

## Peripherals

- 36 GPIOs

## - 4 strapping GPIOs

- SPI, LCD interface, Camera interface, UART, I2C, I2S, remote control, pulse counter, LED PWM, full-speed USB 2.0 OTG, USB Serial/JTAG controller, MCPWM, SD/MMC host controller, GDMA, TWAI ${ }^{\circledR}$ controller (compatible with ISO 11898-1), ADC, touch sensor, temperature sensor, timers and watchdogs

## Integrated Components on Module

- 40 MHz crystal oscillator
- Up to 16 MB Quad SPI flash

## Antenna Options

- ESP32-S3-WROOM-1: On-board PCB antenna
- ESP32-S3-WROOM-1U: External antenna via a connector

## Operating Conditions

- Operating voltage/Power supply: $3.0 \sim 3.6 \mathrm{~V}$
- Operating ambient temperature:
- $65^{\circ} \mathrm{C}$ version: $-40 \sim 65^{\circ} \mathrm{C}$
- $85^{\circ} \mathrm{C}$ version: $-40 \sim 85^{\circ} \mathrm{C}$
- $105^{\circ} \mathrm{C}$ version: $-40 \sim 105^{\circ} \mathrm{C}$

## Certification

- RF certification: See certificates
- Green certification: RoHS/REACH

## Test

- HTOL/HTSL/uHAST/TCT/ESD# 1.2 Series Comparison 

ESP32-S3-WROOM-1 and ESP32-S3-WROOM-1U are two powerful, generic Wi-Fi + Bluetooth LE MCU modules that are built around the ESP32-S3 series of SoCs. On top of a rich set of peripherals, the acceleration for neural network computing and signal processing workloads provided by the SoC make the modules an ideal choice for a wide variety of application scenarios related to AI and Artificial Intelligence of Things (AIoT), such as wake word detection, speech commands recognition, face detection and recognition, smart home, smart appliances, smart control panel, smart speaker, etc.

ESP32-S3-WROOM-1 comes with a PCB antenna. ESP32-S3-WROOM-1U comes with an external antenna connector. A wide selection of module variants are available for customers as shown in Table 1-1 and 1-2. H4 series modules operate at $-40 \sim 105^{\circ} \mathrm{C}$ ambient temperature, R8 and R16V series modules operate at $-40 \sim$ $65^{\circ} \mathrm{C}$ ambient temperature, and other module variants operate at $-40 \sim 85^{\circ} \mathrm{C}$ ambient temperature. For R8 and R16V series modules with Octal SPI PSRAM, if the PSRAM ECC function is enabled, the maximum ambient temperature can be improved to $85^{\circ} \mathrm{C}$, while the usable size of PSRAM will be reduced by $1 / 16$.

Table 1-1. ESP32-S3-WROOM-1 Series Comparison ${ }^{1}$

| Ordering Code ${ }^{2}$ | Flash ${ }^{3,4}$ | PSRAM $^{4}$ | Ambient Temp. ${ }^{5}$ <br> $\left({ }^{\circ} \mathrm{C}\right)$ | Size ${ }^{6}$ <br> (mm) |
| :-- | :--: | :--: | :--: | :--: |
| ESP32-S3-WROOM-1-N4 | 4 MB (Quad SPI) | - | $-40 \sim 85$ |  |
| ESP32-S3-WROOM-1-N8 | 8 MB (Quad SPI) | - | $-40 \sim 85$ |  |
| ESP32-S3-WROOM-1-N16 | 16 MB (Quad SPI) | - | $-40 \sim 85$ |  |
| ESP32-S3-WROOM-1-H4 | 4 MB (Quad SPI) | - | $-40 \sim 105$ |  |
| ESP32-S3-WROOM-1-N4R2 | 4 MB (Quad SPI) | 2 MB (Quad SPI) | $-40 \sim 85$ |  |
| ESP32-S3-WROOM-1-N8R2 | 8 MB (Quad SPI) | 2 MB (Quad SPI) | $-40 \sim 85$ |  |
| ESP32-S3-WROOM-1-N16R2 | 16 MB (Quad SPI) | 2 MB (Quad SPI) | $-40 \sim 85$ |  |
| ESP32-S3-WROOM-1-N4R8 | 4 MB (Quad SPI) | 8 MB (Octal SPI) | $-40 \sim 65$ |  |
| ESP32-S3-WROOM-1-N8R8 | 8 MB (Quad SPI) | 8 MB (Octal SPI) | $-40 \sim 65$ |  |
| ESP32-S3-WROOM-1-N16R8 | 16 MB (Quad SPI) | 8 MB (Octal SPI) | $-40 \sim 65$ |  |
| ESP32-S3-WROOM-1-N16R16VA ${ }^{7}$ | 16 MB (Quad SPI) | 16 MB (Octal SPI) | $-40 \sim 65$ |  |

${ }^{1}$ This table shares the same notes presented in Table 1-2 below.
Table 1-2. ESP32-S3-WROOM-1U Series Comparison

| Ordering Code ${ }^{2}$ | Flash ${ }^{3,4}$ | PSRAM $^{4}$ | Ambient Temp. ${ }^{5}$ <br> $\left({ }^{\circ} \mathrm{C}\right)$ | Size ${ }^{6}$ <br> (mm) |
| :-- | :--: | :--: | :--: | :--: |
| ESP32-S3-WROOM-1U-N4 | 4 MB (Quad SPI) | - | $-40 \sim 85$ |  |
| ESP32-S3-WROOM-1U-N8 | 8 MB (Quad SPI) | - | $-40 \sim 85$ |  |
| ESP32-S3-WROOM-1U-N16 | 16 MB (Quad SPI) | - | $-40 \sim 85$ |  |
| ESP32-S3-WROOM-1U-H4 | 4 MB (Quad SPI) | - | $-40 \sim 105$ |  |
| ESP32-S3-WROOM-1U-N4R2 | 4 MB (Quad SPI) | 2 MB (Quad SPI) | $-40 \sim 85$ |  |
| ESP32-S3-WROOM-1U-N8R2 | 8 MB (Quad SPI) | 2 MB (Quad SPI) | $-40 \sim 85$ |  |
| ESP32-S3-WROOM-1U-N16R2 | 16 MB (Quad SPI) | 2 MB (Quad SPI) | $-40 \sim 85$ |  |
| ESP32-S3-WROOM-1U-N4R8 | 4 MB (Quad SPI) | 8 MB (Octal SPI) | $-40 \sim 65$ |  |
| ESP32-S3-WROOM-1U-N8R8 | 8 MB (Quad SPI) | 8 MB (Octal SPI) | $-40 \sim 65$ |  |
| ESP32-S3-WROOM-1U-N16R8 | 16 MB (Quad SPI) | 8 MB (Octal SPI) | $-40 \sim 65$ |  |
| ESP32-S3-WROOM-1U-N16R16VA ${ }^{7}$ | 16 MB (Quad SPI) | 16 MB (Octal SPI) | $-40 \sim 65$ |  |${ }^{2}$ For customization of ESP32-S3-WROOM-1-H4, ESP32-S3-WROOM-1U-H4, and ESP32-S3-WROOM-1UN16R16VA, please contact us.
${ }^{3}$ By default, the SPI flash on the module operates at a maximum clock frequency of 80 MHz and does not support the auto suspend feature. If you have a requirement for a higher flash clock frequency of 120 MHz or if you need the flash auto suspend feature, please contact us.
${ }^{4}$ The modules use PSRAM integrated in the chip's package. For specifications, refer to Section 6.5 Memory Specifications.
${ }^{5}$ Ambient temperature specifies the recommended temperature range of the environment immediately outside the Espressif module.
${ }^{6}$ For details, refer to Section 10.1 Module Dimensions.
${ }^{7}$ Please note that the VDD_SPI voltage is 1.8 V for ESP32-S3-WROOM-1-N16R16VA and ESP32-S3-WROOM-1U-N16R16VA only.

At the core of the modules is an ESP32-S3 series of SoC, an Xtensa ${ }^{\circledR} 32$-bit LX7 CPU that operates at up to 240 MHz . You can power off the CPU and make use of the low-power co-processor to constantly monitor the peripherals for changes or crossing of thresholds.

# Note: 

For more information on ESP32-S3, please refer to ESP32-S3 Series Datasheet.
For chip revision identification, ESP-IDF release that supports a specific chip revision, and other information on chip revisions, please refer to ESP32-S3 Series SoC Errata > Section Chip Revision Identification.

### 1.3 Applications

- Smart Home
- Industrial Automation
- Health Care
- Consumer Electronics
- Smart Agriculture
- POS Machines
- Service Robot
- Audio Devices
- Generic Low-power loT Sensor Hubs
- Generic Low-power loT Data Loggers
- Cameras for Video Streaming
- USB Devices
- Speech Recognition
- Image Recognition
- Wi-Fi + Bluetooth Networking Card
- Touch and Proximity Sensing# Contents 

1 Module Overview ..... 2
1.1 Features ..... 2
1.2 Series Comparison ..... 3
1.3 Applications ..... 4
2 Block Diagram ..... 9
3 Pin Definitions ..... 10
3.1 Pin Layout ..... 10
3.2 Pin Description ..... 11
4 Boot Configurations ..... 13
4.1 Chip Boot Mode Control ..... 14
4.2 VDD_SPI Voltage Control ..... 15
4.3 ROM Messages Printing Control ..... 15
4.4 JTAG Signal Source Control ..... 15
4.5 Chip Power-up and Reset ..... 16
5 Peripherals ..... 17
5.1 Peripheral Overview ..... 17
5.2 Peripheral Description ..... 17
5.2.1 Connectivity Interface ..... 17
5.2.1.1 UART Controller ..... 17
5.2.1.2 I2C Interface ..... 18
5.2.1.3 I2S Interface ..... 19
5.2.1.4 LCD and Camera Controller ..... 19
5.2.1.5 Serial Peripheral Interface (SPI) ..... 19
5.2.1.6 Two-Wire Automotive Interface (TWAI ${ }^{\circledR}$ ) ..... 22
5.2.1.7 USB 2.0 OTG Full-Speed Interface ..... 23
5.2.1.8 USB Serial/JTAG Controller ..... 24
5.2.1.9 SD/MMC Host Controller ..... 25
5.2.1.10 LED PWM Controller ..... 25
5.2.1.11 Motor Control PWM (MCPWM) ..... 26
5.2.1.12 Remote Control Peripheral (RMT) ..... 26
5.2.1.13 Pulse Count Controller (PCNT) ..... 27
5.2.2 Analog Signal Processing ..... 27
5.2.2.1 SAR ADC ..... 28
5.2.2.2 Temperature Sensor ..... 28
5.2.2.3 Touch Sensor ..... 28
6 Electrical Characteristics ..... 29
6.1 Absolute Maximum Ratings ..... 29
6.2 Recommended Operating Conditions ..... 296.3 DC Characteristics $\left(3.3 \mathrm{~V}, 25^{\circ} \mathrm{C}\right)$ ..... 29
6.4 Current Consumption Characteristics ..... 30
6.4.1 Current Consumption in Active Mode ..... 30
6.4.2 Current Consumption in Other Modes ..... 30
6.5 Memory Specifications ..... 32
7 RF Characteristics ..... 33
7.1 Wi-Fi Radio ..... 33
7.1.1 Wi-Fi RF Transmitter (TX) Characteristics ..... 33
7.1.2 Wi-Fi RF Receiver (RX) Characteristics ..... 34
7.2 Bluetooth LE Radio ..... 35
7.2.1 Bluetooth LE RF Transmitter (TX) Characteristics ..... 36
7.2.2 Bluetooth LE RF Receiver (RX) Characteristics ..... 37
8 Module Schematics ..... 40
9 Peripheral Schematics ..... 42
10 Physical Dimensions ..... 43
10.1 Module Dimensions ..... 43
10.2 Dimensions of External Antenna Connector ..... 44
11 PCB Layout Recommendations ..... 46
11.1 PCB Land Pattern ..... 46
11.2 Module Placement for PCB Design ..... 47
12 Product Handling ..... 48
12.1 Storage Conditions ..... 48
12.2 Electrostatic Discharge (ESD) ..... 48
12.3 Reflow Profile ..... 48
12.4 Ultrasonic Vibration ..... 49
Datasheet Versioning ..... 50
Related Documentation and Resources ..... 51
Revision History ..... 52# List of Tables 

1-1 ESP32-S3-WROOM-1 Series Comparison ${ }^{1}$ ..... 3
1-2 ESP32-S3-WROOM-1U Series Comparison ..... 3
3-1 Pin Definitions ..... 11
4-1 Default Configuration of Strapping Pins ..... 13
4-2 Description of Timing Parameters for the Strapping Pins ..... 14
4-3 Chip Boot Mode Control ..... 14
4-4 VDD_SPI Voltage Control ..... 15
4-5 JTAG Signal Source Control ..... 16
4-6 Description of Timing Parameters for Power-up and Reset ..... 16
6-1 Absolute Maximum Ratings ..... 29
6-2 Recommended Operating Conditions ..... 29
6-3 DC Characteristics (3.3 V, $25^{\circ} \mathrm{C}$ ) ..... 29
6-4 Current Consumption in Avtice Mode ..... 30
6-5 Current Consumption in Modem-sleep Mode ..... 31
6-6 Current Consumption in Low-Power Modes ..... 31
6-7 Flash Specifications ..... 32
6-8 PSRAM Specifications ..... 32
7-1 Wi-Fi RF Characteristics ..... 33
7-2 TX Power with Spectral Mask and EVM Meeting 802.11 Standards ..... 33
7-3 TX EVM Test ${ }^{1}$ ..... 33
7-4 RX Sensitivity ..... 34
7-5 Maximum RX Level ..... 35
7-6 RX Adjacent Channel Rejection ..... 35
7-7 Bluetooth LE RF Characteristics ..... 35
7-8 Bluetooth LE - Transmitter Characteristics - 1 Mbps ..... 36
7-9 Bluetooth LE - Transmitter Characteristics - 2 Mbps ..... 36
7-10 Bluetooth LE - Transmitter Characteristics - 125 Kbps ..... 36
7-11 Bluetooth LE - Transmitter Characteristics - 500 Kbps ..... 37
7-12 Bluetooth LE - Receiver Characteristics - 1 Mbps ..... 37
7-13 Bluetooth LE - Receiver Characteristics - 2 Mbps ..... 37
7-14 Bluetooth LE - Receiver Characteristics - 125 Kbps ..... 38
7-15 Bluetooth LE - Receiver Characteristics - 500 Kbps ..... 38# List of Figures 

2-1 ESP32-S3-WROOM-1 Block Diagram ..... 9
2-2 ESP32-S3-WROOM-1U Block Diagram ..... 9
3-1 Pin Layout (Top View) ..... 10
4-1 Visualization of Timing Parameters for the Strapping Pins ..... 14
4-2 Visualization of Timing Parameters for Power-up and Reset ..... 16
8-1 ESP32-S3-WROOM-1 Schematics ..... 40
8-2 ESP32-S3-WROOM-1U Schematics ..... 41
9-1 Peripheral Schematics ..... 42
10-1 ESP32-S3-WROOM-1 Physical Dimensions ..... 43
10-2 ESP32-S3-WROOM-1U Physical Dimensions ..... 43
10-3 Dimensions of External Antenna Connector ..... 44
11-1 ESP32-S3-WROOM-1 Recommended PCB Land Pattern ..... 46
11-2 ESP32-S3-WROOM-1U Recommended PCB Land Pattern ..... 47
12-1 Reflow Profile ..... 48# 2 Block Diagram 



Figure 2-1. ESP32-S3-WROOM-1 Block Diagram


Figure 2-2. ESP32-S3-WROOM-1U Block Diagram

## Note:

For the pin mapping between the chip and the in-package PSRAM, please refer to ESP32-S3 Series Datasheet > Table Pin Mapping Between Chip and In-package Flash/PSRAM.# 3 Pin Definitions
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

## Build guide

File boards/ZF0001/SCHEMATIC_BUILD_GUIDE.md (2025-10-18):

# ZF0001 Schematic Build Guide

**Complete pin-by-pin assembly instructions**

---

## Overview - System Block Diagram

```mermaid
graph TB
    subgraph "POWER SECTION"
        J_BAT[J_BAT<br/>Battery Connector]
        Q_BAT[Q_BAT_PROT<br/>P-FET]
        SW_PWR[SW_PWR<br/>Slide Switch]
        Q_PWR[Q_PWR<br/>Power Switch]
        U_CHARGER[U_CHARGER<br/>BQ24075]
        U_BUCKBOOST[U_BUCKBOOST<br/>TPS63070]
        USB[USB<br/>USB-C Module]
    end
    
    subgraph "MAIN CONTROLLER"
        U_MCU[U_MCU<br/>ESP32-S3-WROOM-1]
    end
    
    subgraph "PERIPHERALS"
        U_FUELGAUGE[U_FUELGAUGE<br/>MAX17048]
        U_GNSS[U_GNSS<br/>MAX-M10S]
        MIC[MIC Module<br/>Audio Jack + OPA344]
        J_SD[J_SD<br/>MicroSD]
    end
    
    subgraph "USER INTERFACE"
        BUTTONS[SW_BOOT<br/>SW_RESET<br/>SW_RECORD]
        LEDS[LED_R<br/>LED_G<br/>LED_B<br/>LED_PWR]
    end
    
    J_BAT --> Q_BAT --> Q_PWR
    SW_PWR -.controls.-> Q_PWR
    Q_PWR --> U_CHARGER
    USB --> U_CHARGER
    U_CHARGER --> U_BUCKBOOST
    U_BUCKBOOST --> U_MCU
    U_BUCKBOOST --> U_FUELGAUGE
    U_BUCKBOOST --> U_GNSS
    U_BUCKBOOST --> MIC
    U_BUCKBOOST --> J_SD
    U_BUCKBOOST --> LEDS
    
    U_MCU <--> U_FUELGAUGE
    U_MCU <--> U_GNSS
    U_MCU <--> J_SD
    U_MCU <-- MIC
    U_MCU --> LEDS
    BUTTONS --> U_MCU
```

---

## Power Section (Build First)

### 1. Battery Connector - J_BAT (S2B-PH-K-S)

```
Component: J_BAT
Part: S2B-PH-K-S (JST-PH 2-pin)

Connections:
Pin 1 (P1) → Net: VBAT_UNFUSED (before fuse)
Pin 2 (P2) → GND
```

**Battery Overcurrent Protection - F_BAT:**
```
Component: F_BAT
Part: 0Ω resistor footprint (1206) or PPTC fuse

Connections:
P1 → VBAT_UNFUSED (from battery)
P2 → VBAT_INPUT (to protection FET)

Recommended PPTC: Littelfuse 0ZCJ0200FF2E (2A hold, 4A trip)
Note: Can populate with 0Ω resistor if overcurrent protection not needed
```

### 2. Battery Protection - Q_BAT_PROT (DMG2305UX-7)

```
Component: Q_BAT_PROT  
Part: DMG2305UX-7 (P-channel MOSFET, SOT-23)

Pinout (SOT-23):
Pin 1: Gate (G)
Pin 2: Source (S)  
Pin 3: Drain (D)

Connections:
G (Pin 1) → GND                    ← CRITICAL: Gate to ground!
S (Pin 2) → VBAT_INPUT             ← From battery connector
D (Pin 3) → VBAT_RAW               ← Protected battery output

Purpose: Reverse polarity protection via body diode
```

```mermaid
graph LR
    BAT[Battery +] --> S
    S[Source] --> Q[Q_BAT_PROT<br/>P-FET]
    Q --> D[Drain]
    D --> VBAT[VBAT_RAW]
    G[Gate] --> GND
    
    style Q fill:#f96
```

### 3. Power Switch - SW_PWR + Q_PWR

**Slide Switch - SW_PWR (CSS-1210TB):**
```
Component: SW_PWR
Part: CSS-1210TB (SPDT slide switch)

Connections:
Pin 1 (P1)  → GND
Pin 2 (P2)  → SW_GATE (common/wiper)
Pin 3 (P3)  → VBAT_RAW
MH1, MH2    → GND (mounting holes)
```

**Power Switch P-FET - Q_PWR (DMG2305UX-7):**
```
Component: Q_PWR
Part: DMG2305UX-7

Connections:
G (Pin 1) → SW_GATE                ← Controlled by slide switch
S (Pin 2) → VBAT_RAW               ← From protected battery
D (Pin 3) → VBAT_SWITCHED          ← To charger battery input
```

**Gate Pull-up - R_GATE_PU:**
```
Component: R_GATE_PU
Value: 100kΩ 5%
Package: 0402

P1 → VBAT_RAW
P2 → SW_GATE

Purpose: Pulls gate HIGH (OFF) when switch is open
```

**Operation:**
```
Switch LEFT  → SW_GATE = GND         → Vgs=-3.7V → P-FET ON  → System ON
Switch RIGHT → SW_GATE = VBAT_RAW    → Vgs=0V    → P-FET OFF → System OFF
```

### 4. USB-C Connector - USB Module

```
Component: USB (UsbC module from registry)
Instantiation:
    name = "USB"
    config_usb_type = "USB2_SINK"
    config_use_usb_power = True
    vusb = VBUS_5V      ← Create this power rail
    usb2 = usb_data     ← Create Usb2("USB_DATA")
    gnd = GND

This module includes:
- HRO TYPE-C-31-M-12 connector
- 2× 5.1kΩ CC resistors (for USB2 sink)
- TPD4E05U06QDQARQ1 (ESD protection on D+/D-)
- SMF6.0CA (TVS diode on VBUS)
```

### 5. Battery Charger - U_CHARGER (BQ24075RGTR)

```
Component: U_CHARGER
Part: BQ24075RGTR (QFN-16, 3mm×3mm)

Power Connections:
Pin 13 (IN)      → VBUS_5V          ← From USB-C
Pin 2,3 (BAT)    → VBAT_SWITCHED    ← From power switch
Pin 10,11 (OUT)  → VSYS             ← System power output
Pin 1 (VSS)      → GND
Pin 15 (GND)     → GND              ← Thermal pad

Programming Resistors (all to GND):
Pin 16 (ISET) → R_ISET (1.13kΩ 1%) → GND    [800mA charge current]
Pin 12 (ILIM) → R_ILIM (1.18kΩ 1%) → GND    [1.3A input limit]
Pin 14 (TMR)  → R_TMR (46.4kΩ 5%) → GND     [6.25hr timer]
Pin 8 (TS)    → R_TS (10kΩ 5%) → GND         [NTC disabled]

Control Pins (all with 100kΩ to GND):
Pin 4 (CE)     → R_CE (100kΩ) → GND          [Charge enabled]
Pin 6 (EN1)    → R_EN1 (100kΩ) → GND         [EN1=0, EN2=0 = ILIM mode]
Pin 5 (EN2)    → R_EN2 (100kΩ) → GND
Pin 14 (SYSOFF) → R_SYSOFF (100kΩ) → GND    [Normal operation]

Status Outputs (open-drain, need pull-ups):
Pin 9 (CHG)    → R_CHG (100kΩ) → VSYS → Gpio("CHG_STAT")
Pin 7 (PGOOD)  → R_PG (100kΩ) → VSYS → Gpio("PG_STAT")

Bypass Capacitors:
C_IN:  10µF 10V 0805, IN to GND
C_BAT: 10µF 10V 0805, BAT to GND  
C_SYS: 10µF 10V 0805, OUT to GND
```

```mermaid
graph TB
    VBUS[USB 5V] --> IN
    VBAT_SW[VBAT_SWITCHED] --> BAT
    
    subgraph "U_CHARGER BQ24075"
        IN[IN<br/>Pin 13]
        BAT[BAT<br/>Pins 2,3]
        OUT[OUT<br/>Pins 10,11]
        ISET[ISET<br/>Pin 16]
        ILIM[ILIM<br/>Pin 12]
    end
    
    OUT --> VSYS[VSYS<br/>System Power]
    
    ISET --> R_ISET[1.13kΩ] --> GND
    ILIM --> R_ILIM[1.18kΩ] --> GND
    
    style IN fill:#faa
    style BAT fill:#fda
    style OUT fill:#afa
```

### 6. Buck-Boost Converter - U_BUCKBOOST (TPS63070RNMR)

```
Component: U_BUCKBOOST
Part: TPS63070RNMR (VQFN-15, 2.5mm×3mm)

Power Connections:
Pin 12,13 (VIN)   → VSYS            ← From charger
Pin 7,8 (VOUT)    → VDD_3V3         ← 3.3V output
Pin 4 (GND)       → GND             ← Logic ground
Pin 10 (PGND)     → GND             ← Power ground (thermal)

Inductor:
Pin 11 (L1) ──┐
              ├── L_MAIN (1.5µH, 4A, 1210)
Pin 9 (L2)  ──┘

Feedback Divider (for 3.3V output):
Pin 5 (FB) → R_FBT (316kΩ 1%) → VOUT
           → R_FBB (100kΩ 1%) → GND
NOTE: V_FB = 0.8V reference!

Control Pins:
Pin 14 (EN)    → R_EN (100kΩ) → VSYS → Gpio("BUCKBOOST_EN")
Pin 2 (PG)     → R_PG (100kΩ) → VOUT → Gpio("BUCKBOOST_PG")
Pin 1 (PS/S)   → R_PS (100kΩ) → VSYS  [Auto PWM/PFM mode]
Pin 15 (VSEL)  → R_VSEL (0Ω) → GND    [Voltage scaling disabled]
Pin 6 (FB2)    → R_FB2 (0Ω) → GND     [Not used]

VAUX (Internal LDO):
Pin 3 (VAUX) → C_VAUX (100nF 0402) → GND

Bypass Capacitors:
C_IN:   10µF 25V 0805, VIN to GND
C_OUT1: 47µF 10V 1206, VOUT to GND
C_OUT2: 47µF 10V 1206, VOUT to GND
```

```mermaid
graph TB
    VSYS[VSYS<br/>3.0-5V] --> VIN
    
    subgraph "U_BUCKBOOST TPS63070"
        VIN[VIN<br/>Pins 12,13]
        L1[L1<br/>Pin 11]
        L2[L2<br/>Pin 9]
        VOUT[VOUT<br/>Pins 7,8]
        FB[FB<br/>Pin 5]
    end
    
    L1 --> INDUCTOR[1.5µH] --> L2
    VOUT --> V33[VDD_3V3<br/>3.3V]
    
    FB --> R_FBT[316kΩ] --> VOUT
    FB --> R_FBB[100kΩ] --> GND
    
    style VIN fill:#faa
    style VOUT fill:#afa
```

---

## ESP32-S3 Section

### 7. Main Controller - U_MCU (ESP32-S3-WROOM-1-N8R8)

```
Component: U_MCU
Part: ESP32-S3-WROOM-1-N8R8 (41-pin module)

Power Pins:
Pin 2 (3V3)     → VDD_3V3
Pin 1,40,41 (GND+EPAD) → GND (all 11 GND pins)
  - Pins: 1, 15, 18, 21, 23, 28, 31, 34, 37, 40, 41 (EPAD)

Control Pins:
Pin 3 (EN)      → Gpio("ESP_EN") with R_EN (10kΩ) + C_EN (1µF) to GND

USB Pins:
Pin 13 (IO19)   → usb_data.DM (USB D-)
Pin 14 (IO20)   → usb_data.DP (USB D+)

Boot Pins:
Pin 27 (IO0)    → Gpio("ESP_BOOT") with R_GPIO0 (10kΩ to VDD_3V3)

GPIO Assignments (pin → signal):
Pin 39 (IO1)   → Gpio("MIC_IN")         # ADC1_CH0 for microphone
Pin 38 (IO2)   → Gpio("BTN_RECORD")     # Record button input
Pin 4 (IO4)    → Gpio("LED_R")          # Red LED output
Pin 5 (IO5)    → Gpio("LED_G")          # Green LED output  
Pin 6 (IO6)    → Gpio("LED_B")          # Blue LED output
Pin 7 (IO7)    → Gpio("CHG_STAT")       # Charger status input
Pin 12 (IO8)   → Gpio("PG_STAT")        # Power good input
Pin 17 (IO9)   → Gpio("FG_ALERT")       # Fuel gauge alert input
Pin 18 (IO10)  → spi_sd.CS              # SD card chip select
Pin 19 (IO11)  → spi_sd.MOSI            # SD card MOSI
Pin 20 (IO12)  → spi_sd.CLK             # SD card clock
Pin 21 (IO13)  → spi_sd.MISO            # SD card MISO
Pin 22 (IO14)  → Gpio("SD_DETECT")      # SD card detect
Pin 8 (IO15)   → uart_gnss.TX           # GPS UART TX (ESP→GNSS)
Pin 9 (IO16)   → uart_gnss.RX           # GPS UART RX (ESP←GNSS)
Pin 23 (IO21)  → i2c_main.SDA           # I2C data
Pin 24 (IO47)  → i2c_main.SCL           # I2C clock

PSRAM Pins (DO NOT USE):
Pin 28 (IO35) → Internal PSRAM
Pin 29 (IO36) → Internal PSRAM  
Pin 30 (IO37) → Internal PSRAM

Unused Pins (leave as NC):
Pin 15 (IO3)   → Will have 10kΩ pull-up in ESP32S3WROOM1x module
Pin 26 (IO45)  → Internal pull-down (VDD_SPI strapping)
Pin 16 (IO46)  → Internal pull-down (ROM print strapping)
```

**Module Internal Connections (ESP32S3WROOM1x.zen adds):**
- R_EN: 10kΩ from VDD_3V3 to EN
- C_EN: 1µF from EN to GND
- R_GPIO0: 10kΩ from VDD_3V3 to IO0
- R_GPIO3_STRAP: 10kΩ from VDD_3V3 to IO3
- C_VDD1: 10µF from VDD_3V3 to GND
- C_VDD2,3: 100nF from VDD_3V3 to GND

### 8. Boot/Reset Buttons

```
SW_BOOT:
Component: SW_BOOT
Part: SKRKAHE020 (Tactile button)
P1 → Gpio("ESP_BOOT") (already has pull-up)
P2 → GND

SW_RESET:
Component: SW_RESET  
Part: SKRKAHE020
P1 → Gpio("ESP_EN") (already has pull-up in module)
P2 → GND
```

---

## I2C Section

### 9. I2C Bus Configuration

```
Create I2C interface: i2c_main = I2c("I2C_MAIN")

Pull-up Resistors (CRITICAL - pull to VDD_3V3, NOT VBAT_RAW):
R_I2C_SDA: 4.7kΩ 5% 0402
    P1 → i2c_main.SDA
    P2 → VDD_3V3

R_I2C_SCL: 4.7kΩ 5% 0402
    P1 → i2c_main.SCL  
    P2 → VDD_3V3
```

### 10. Fuel Gauge - U_FUELGAUGE (MAX17048X+T10)

```
Component: U_FUELGAUGE
Part: MAX17048X+T10 (8-WLCSP, 1.66mm×0.92mm)

Pinout (BGA):
A1: CTG
A2: CELL
A3: VDD
A4: GND
B1: SDA
B2: SCL
B3: QSTRT
B4: ALRT

Connections:
A1 (CTG)   → C_CTG (100nF 0402) → GND
A2 (CELL)  → VBAT_RAW               ← Monitors battery directly
A3 (VDD)   → VDD_3V3                ← CRITICAL: Not VBAT_RAW!
A4 (GND)   → GND
B1 (SDA)   → i2c_main.SDA           ← To ESP32 GPIO21
B2 (SCL)   → i2c_main.SCL           ← To ESP32 GPIO47
B3 (QSTRT) → Leave floating          [Quick start, auto mode]
B4 (ALRT)  → Gpio("FG_ALERT")       ← To ESP32 GPIO9 (no external pull-up)

Bypass:
C_VDD: 100nF 0402, VDD to GND

NOTE: VDD on VDD_3V3 (not VBAT_RAW) to match I2C pull-up domain!
      This prevents ESP32 GPIO overvoltage (4.2V > 3.6V max spec)
```

---

## GPS Section

### 11. GNSS Module - U_GNSS (MAX-M10S-00B)

```
Component: U_GNSS
Part: MAX-M10S-00B (LGA-18)

Power Pins:
Pin 8 (VCC)      → VDD_3V3
Pin 7 (V_IO)     → Via R_VIO (0Ω) to VCC  [Tied together for 3.3V]
Pin 6 (V_BCKP)   → NOT CONNECTED           [Would exceed 3.6V spec]
Pin 14 (VCC_RF)  → C_VCCRF (100nF) → GND  [For active antenna]
Pin 1,10,12 (GND) → GND (all 3 GND pins)

UART:
Pin 2 (TXD)      → uart_gnss.TX            ← GNSS transmits to ESP32 GPIO16
Pin 3 (RXD)      → uart_gnss.RX            ← GNSS receives from ESP32 GPIO15

RF:
Pin 11 (RF_IN)   → u.FL connector (in module)

Control (optional, connected but not used in firmware):
Pin 9 (RESET_N)  → Gpio("GNSS_RESET")     [Has internal pull-up, can leave]
Pin 4 (TIMEPULSE)→ Gpio("GNSS_PPS")       [Time pulse output]

I2C (not used):
Pin 16 (SDA)     → Leave open
Pin 17 (SCL)     → Leave open

Special Pins:
Pin 18 (SAFEBOOT_N) → Leave open          [Normal boot]
Pin 15 (VIO_SEL)    → Leave open          [3.3V mode]
Pin 5 (EXTINT)      → Leave open
Pin 13 (LNA_EN)     → Leave open          [Controls internal/external LNA]
Pin ? (RESERVED)    → Leave floating      [Per datasheet]

Module adds (MAXM10Sx.zen):
- R_VIO: 0Ω from VCC to V_IO
- C_VCC1: 10µF VCC to GND
- C_VCC2: 100nF VCC to GND
- C_VCCRF: 100nF VCC_RF to GND
```

---

## Audio Section

### 12. Analog Power Filtering

```
Ferrite Bead - FB_ANA:
Component: FB_ANA
Value: 10µH 500mA 0805
P1 → VDD_3V3
P2 → VDD_3V3_ANA

Filter Cap - C_ANA_FILT:
Value: 10µF 10V 0805
P1 → VDD_3V3_ANA
P2 → GND

Purpose: Isolates analog circuit from digital switching noise
```

### 13. Microphone Input - MIC Module (AnalogMicInput)

**Audio Jack - J_MIC (SJ-3524-SMT-TR):**
```
Component: J_MIC (inside MIC module)
Part: SJ-3524-SMT-TR (3.5mm TRS jack)

Pin 2 (TIP)    → _MIC_IN             ← Microphone signal
Pin 3 (RING)   → GND                 [Not used for mono]
Pin 1 (SLEEVE) → GND
Pin 4 (TIP_SW) → Leave NC            [Tip switch not used]
Pin 5,6        → GND                 [Mechanical ground]
```

**Microphone Bias Network:**
```
R_BIAS1: 2.2kΩ 5% 0402
    P1 → VDD_3V3_ANA
    P2 → _MIC_BIAS

R_BIAS2: 2.2kΩ 5% 0402
    P1 → _MIC_BIAS
    P2 → GND

C_BIAS: 10µF 10V 0805
    P1 → _MIC_BIAS
    P2 → GND

Result: MIC_BIAS = 1.65V (VDD/2)

R_MIC: 2.2kΩ 5% 0402
    P1 → _MIC_BIAS
    P2 → _MIC_IN

Purpose: Provides DC bias voltage to electret microphone
```

**AC Coupling:**
```
C_AC: 1µF 10V 0402
    P1 → _MIC_IN
    P2 → _MIC_AC

R_IN: 10kΩ 5% 0402
    P1 → _MIC_AC
    P2 → _OPAMP_VREF
```

**Op-Amp Reference (Virtual Ground):**
```
R_VREF1: 10kΩ 5% 0402
    P1 → VDD_3V3_ANA
    P2 → _OPAMP_VREF

R_VREF2: 10kΩ 5% 0402
    P1 → _OPAMP_VREF
    P2 → GND

C_VREF: 10µF 10V 0805
    P1 → _OPAMP_VREF
    P2 → GND

Result: OPAMP_VREF = 1.65V (VDD/2)
```

**Op-Amp - U_OPAMP (OPA344NA/250):**
```
Component: U_OPAMP (inside MIC module)
Part: OPA344NA/250 (SOT-23-5)

Pinout:
Pin 1: OUT
Pin 2: V- (VM)
Pin 3: +IN (PIN)
Pin 4: -IN (MIN)
Pin 5: V+ (VP)

Connections:
Pin 5 (V+)  → VDD_3V3_ANA
Pin 2 (V-)  → GND
Pin 3 (+IN) → _MIC_AC               ← Input signal
Pin 4 (-IN) → _OPAMP_NEG            ← Feedback
Pin 1 (OUT) → _OPAMP_OUT

Decoupling:
C_OPAMP: 100nF 0402, V+ to GND
```

**Gain Network (Non-inverting, Gain=20):**
```
R_GAIN1: 19kΩ 1% 0402
    P1 → _OPAMP_OUT
    P2 → _OPAMP_NEG

R_GAIN2: 1kΩ 1% 0402
    P1 → _OPAMP_NEG
    P2 → _OPAMP_VREF

Gain = 1 + R_GAIN1/R_GAIN2 = 1 + 19/1 = 20 (26dB)
```

**Output to ADC:**
```
C_OUT: 1µF 10V 0402
    P1 → _OPAMP_OUT
    P2 → mic_out

R_OUT: 10kΩ 5% 0402
    P1 → mic_out
    P2 → GND

mic_out → Connects to Gpio("MIC_IN") = ESP32 GPIO1
```

**Complete Audio Signal Chain:**
```mermaid
graph LR
    MIC[Electret Mic] --> JACK[3.5mm Jack<br/>TIP]
    JACK --> BIAS[DC Bias<br/>1.65V]
    BIAS --> AC[AC Couple<br/>1µF]
    AC --> OPAMP[OPA344<br/>Gain=20]
    OPAMP --> OUT[AC Couple<br/>1µF]
    OUT --> ADC[ESP32 GPIO1<br/>ADC1_CH0]
    
    style OPAMP fill:#f96
    style ADC fill:#69f
```

---

## SD Card Section

### 14. MicroSD Socket - J_SD (MSD-12-A)

```
Component: J_SD
Part: MSD-12-A (MicroSD connector)

Power:
Pin 4 (VDD) → VDD_3V3
Pin 6 (VSS) → GND
Pin 9-15 (GND shields) → GND (all 7 ground pins)

SPI Connections (in SPI mode):
Pin 5 (CLK)     → spi_sd.CLK        ← ESP32 GPIO12
Pin 3 (CMD)     → spi_sd.MOSI       ← ESP32 GPIO11 (CMD in SD = MOSI in SPI)
Pin 2 (CD/DAT3) → spi_sd.CS         ← ESP32 GPIO10 (DAT3 in SD = CS in SPI)
Pin 7 (DAT0)    → spi_sd.MISO       ← ESP32 GPIO13 (DAT0 in SD = MISO in SPI)
Pin 8 (DAT1)    → Net("SD_DAT1")    [Not used in SPI mode]
Pin 1 (DAT2)    → Net("SD_DAT2")    [Not used in SPI mode]
Pin CD1 (detect)→ Gpio("SD_DETECT") ← ESP32 GPIO14

Pull-up Resistors (all to VDD_3V3):
R_SD_CS:     10kΩ 5% 0402, CS to VDD_3V3
R_SD_DAT1:   47kΩ 5% 0402, DAT1 to VDD_3V3
R_SD_DAT2:   47kΩ 5% 0402, DAT2 to VDD_3V3
R_SD_DETECT: 47kΩ 5% 0402, SD_DETECT to VDD_3V3
```

---

## User Interface

### 15. Record Button

```
R_BTN_RECORD: 10kΩ 5% 0402
    P1 → VDD_3V3
    P2 → Gpio("BTN_RECORD")

SW_RECORD:
Part: SKRKAHE020
    P1 → Gpio("BTN_RECORD")
    P2 → GND

Logic: Normally HIGH (pulled up), LOW when pressed
```

### 16. RGB LEDs (Common-Cathode)

**Red LED:**
```
R_LED_R: 150Ω 5% 0402
    P1 → Gpio("LED_R")           ← ESP32 GPIO4
    P2 → LED_R_ANODE

LED_R: Red 0603
    A (Anode)  → LED_R_ANODE
    K (Cathode)→ GND

Current: (3.3V - 2.0V) / 150Ω = 8.7mA
```

**Green LED:**
```
R_LED_G: 47Ω 5% 0402
    P1 → Gpio("LED_G")           ← ESP32 GPIO5
    P2 → LED_G_ANODE

LED_G: Green 0603
    A → LED_G_ANODE
    K → GND

Current: (3.3V - 3.0V) / 47Ω = 6.4mA
```

**Blue LED:**
```
R_LED_B: 47Ω 5% 0402
    P1 → Gpio("LED_B")           ← ESP32 GPIO6
    P2 → LED_B_ANODE

LED_B: Blue 0603
    A → LED_B_ANODE
    K → GND

Current: (3.3V - 3.0V) / 47Ω = 6.4mA
```

**Power LED:**
```
R_LED_PWR: 150Ω 5% 0402
    P1 → VDD_3V3                 ← Always-on indicator
    P2 → LED_PWR_ANODE

LED_PWR: Green 0603
    A → LED_PWR_ANODE
    K → GND

Current: (3.3V - 3.0V) / 150Ω = 2mA
```

---

## Bulk Decoupling

### 17. Power Rail Bulk Capacitors

```
C_BULK_3V3: 100µF 10V 1206
    P1 → VDD_3V3
    P2 → GND

C_BULK_VSYS: 47µF 10V 0805
    P1 → VSYS
    P2 → GND

C_BULK_VBAT: 10µF 10V 0805
    P1 → VBAT_RAW
    P2 → GND

Purpose: Low-frequency energy storage, reduce voltage ripple
```

---

## Test Points

### 18. Test Points (6 total)

```
All test points: variant = "Pad_D1.0mm"

TP_VBAT:     P1 → VBAT_RAW
TP_VSYS:     P1 → VSYS
TP_3V3:      P1 → VDD_3V3
TP_I2C_SDA:  P1 → i2c_main.SDA
TP_I2C_SCL:  P1 → i2c_main.SCL
TP_GND:      P1 → GND

Purpose: Debugging with multimeter/oscilloscope
```

---

## Power Rail Summary

```mermaid
graph TB
    BAT[Battery<br/>3.0-4.2V] --> QPROT[Q_BAT_PROT]
    QPROT --> VBAT[VBAT_RAW]
    VBAT --> QPW[Q_PWR<br/>Switch]
    QPW --> VBATSW[VBAT_SWITCHED]
    
    USB[USB 5V] --> VBUS[VBUS_5V]
    
    VBATSW --> CHG[BQ24075<br/>Charger]
    VBUS --> CHG
    CHG --> VSYS[VSYS<br/>3.7-5V]
    
    VSYS --> BB[TPS63070<br/>Buck-Boost]
    BB --> V33[VDD_3V3<br/>3.3V]
    V33 --> FB[Ferrite<br/>Bead]
    FB --> VANA[VDD_3V3_ANA<br/>3.3V Filtered]
    
    V33 --> ESP[ESP32-S3]
    V33 --> GPS[MAX-M10S]
    V33 --> FG[MAX17048]
    V33 --> SD[SD Card]
    V33 --> LED[LEDs]
    VANA --> MIC[Microphone<br/>Circuit]
    
    style VBAT fill:#faa
    style VSYS fill:#fda
    style V33 fill:#afa
    style VANA fill:#9f9
```

---

## Component Placement Recommendations

### Critical Placement Rules:

**1. Power Section (Bottom-Left):**
```
[J_BAT] → [Q_BAT_PROT] → [SW_PWR + Q_PWR] → [U_CHARGER BQ24075]
Keep short, wide traces (0.5mm+)
```

**2. Buck-Boost (Center-Left):**
```
[U_BUCKBOOST TPS63070]
- Place L_MAIN inductor <5mm from L1/L2 pins
- C_OUT caps <5mm from VOUT pins
- Keep switching node (L1/L2) traces short
```

**3. ESP32 (Center):**
```
[U_MCU ESP32-S3]
- Orient antenna towards board edge (top-right)
- 5mm keep-out zone around antenna
- USB connector near GPIO19/20
```

**4. Microphone (Top-Left, AWAY from switchers):**
```
[J_MIC Audio Jack] → [Bias Network] → [U_OPAMP] → [ESP32 GPIO1]
- >20mm from U_BUCKBOOST
- >15mm from ESP32 WiFi antenna
- VDD_3V3_ANA separate from VDD_3V3
```

**5. GPS (Top-Right):**
```
[U_GNSS MAX-M10S] with u.FL connector
- Clear area for antenna
- >15mm from ESP32 WiFi
```

**6. SD Card (Right):**
```
[J_SD MicroSD Socket]
- Near ESP32 SPI pins
- Accessible for card insertion
```

---

## Net Names Reference

**Power Rails (6 total):**
```
VBUS_5V          - USB 5V input
VBAT_RAW         - Battery after protection (always-on)
VBAT_SWITCHED    - Switched battery to charger
VSYS             - Charger output (3.7-5V)
VDD_3V3          - Main 3.3V rail
VDD_3V3_ANA      - Filtered 3.3V for analog
GND              - Ground
```

**Interface Buses:**
```
usb_data         - Usb2("USB_DATA")
uart_gnss        - Uart("UART_GNSS")
spi_sd           - Spi("SPI_SD")
i2c_main         - I2c("I2C_MAIN")
```

**GPIO Signals:**
```
MIC_IN           - GPIO1 (ADC input)
BTN_RECORD       - GPIO2
LED_R, LED_G, LED_B - GPIO4,5,6
CHG_STAT, PG_STAT - GPIO7,8
FG_ALERT         - GPIO9
SD_DETECT        - GPIO14
GNSS_RESET, GNSS_PPS - Not used in firmware
BUCKBOOST_EN, BUCKBOOST_PG - Not used in firmware
ESP_EN, ESP_BOOT - Reset/boot buttons
```

---

## Critical Notes for Schematic Entry

### ⚠️ **CRITICAL - Do Not Make These Mistakes:**

1. **TPS63070 Feedback:**
   - V_FB = 0.8V (NOT 1.229V!)
   - R_FBT = 316kΩ (NOT 169kΩ!)
   
2. **I2C Pull-ups:**
   - Pull to VDD_3V3 (NOT VBAT_RAW!)
   - ESP32 GPIO max = 3.6V, VBAT can be 4.2V
   
3. **GPIO3 Strapping:**
   - MUST have 10kΩ pull-up (cannot float!)
   - ESP32 datasheet explicitly requires this
   
4. **P-FET Gates:**
   - Q_BAT_PROT gate to GND (NOT floating!)
   - Q_PWR gate to SW_GATE with pull-up
   
5. **MAX17048 VCC:**
   - VCC to VDD_3V3 (NOT VBAT_RAW!)
   - CELL to VBAT_RAW for monitoring

### ✅ **Verification Checklist:**

- [ ] All power rails named correctly
- [ ] All GND pins connected (ESP32 has 11!)
- [ ] I2C pull-ups to VDD_3V3
- [ ] Feedback resistors match formulas
- [ ] GPIO3 has pull-up resistor
- [ ] All buttons have pull-ups
- [ ] All LEDs have current-limiting resistors
- [ ] SD card has all pull-ups
- [ ] Thermal pads connected to GND
- [ ] No floating inputs

---

**This guide ensures your schematic matches the verified design exactly.**

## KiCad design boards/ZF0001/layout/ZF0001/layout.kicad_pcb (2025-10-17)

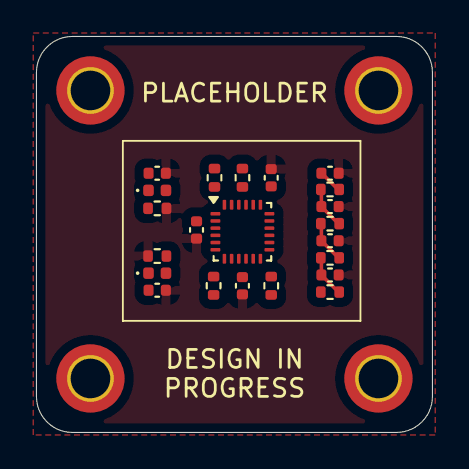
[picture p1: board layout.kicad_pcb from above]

Board: 4 copper layers, 22.0 x 22.0 mm, 26 parts (0 on the bottom side), 13 nets.

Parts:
C1, C2, C3, C9: 100nF; C_0402_1005Metric
C4, C5, C6, C7, C8: 10nF; C_0402_1005Metric
D1, D2: LED GREEN; LED_0402_1005Metric
H1, H2, H3, H4: M2 DIN965 TopBottom; MountingHole_2.2mm_M2_DIN965_Pad_TopBottom
R1, R10: 1k; R_0402_1005Metric
R2, R3: 4.7k; R_0402_1005Metric
R4, R5: 10k; R_0402_1005Metric
R6, R7, R8, R9: 820; R_0402_1005Metric
U1: ?; InvenSense_QFN-24_3x3mm_P0.4mm

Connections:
Imu.LED.L: D1.1, R1.1
Imu.MPU9250.CS_PULLUP: R4.1, U1.22
Imu.MPU9250.REGOUT: C2.1, U1.10
Imu.NC: R3.1, U1.21
Imu.NC_2: R2.1, U1.7
LowPassFilter.STAGE1_OUT: C5.1, R6.2, R7.1
LowPassFilter.STAGE2_OUT: C6.1, R7.2, R8.1
LowPassFilter.STAGE3_OUT: C7.1, R8.2, R9.1
MCU_IN: C8.1, R9.2
PowerLed.L: D2.1, R10.1
SENSOR_OUT: R5.1, R6.1, U1.12
gnd_GND: C1.2, C2.2, C3.2, C4.2, C5.2, C6.2, C7.2, C8.2, C9.2, R1.2, R10.2, U1.9, U1.18, U1.20
vcc_VCC: C1.1, C3.1, C4.1, C9.1, D1.2, D2.2, R2.2, R3.2, R4.2, R5.2, U1.1, U1.8, U1.13

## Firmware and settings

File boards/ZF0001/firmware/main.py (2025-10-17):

"""
ZF0001 Wearable Voice Logger - Main Application

Records audio, tags with GPS and battery data, streams to server via WiFi
"""
import time
import gc
from machine import Pin

# Import configuration
import config

# Import modules
from lib.hardware import LED, Button, StatusPins
from lib.audio import Audio
from lib.gps import GPS
from lib.battery import Battery
from lib.network import Network
from lib.storage import SDCard

print("\n" + "="*40)
print("ZF0001 Wearable Voice Logger")
print("="*40)
print(f"Device ID: {config.DEVICE_ID}")
print(f"Firmware: MicroPython v1.0.0")
print("="*40 + "\n")

# ============================================================================
# Initialize Hardware
# ============================================================================
print("[INIT] Initializing hardware...")

# LEDs
led = LED(config.PINS['LED_RED'], config.PINS['LED_GREEN'], config.PINS['LED_BLUE'])
led.set(True, False, False)  # Red
time.sleep(0.2)
led.set(False, True, False)  # Green
time.sleep(0.2)
led.set(False, False, True)  # Blue
time.sleep(0.2)
led.off()

# Buttons
btn_record = Button(config.PINS['BTN_RECORD'])

# Status pins
status = StatusPins(
    config.PINS['CHG_STAT'],
    config.PINS['PG_STAT'],
    config.PINS['FG_ALERT']
)

# ============================================================================
# Initialize Peripherals
# ============================================================================
print("[INIT] Initializing peripherals...")

# Audio
audio = Audio(
    config.PINS['MIC_ADC'],
    config.AUDIO_SAMPLE_RATE,
    config.AUDIO_BUFFER_SIZE
)

# GPS
gps = GPS(
    config.PINS['GPS_TX'],
    config.PINS['GPS_RX'],
    config.GPS_BAUD_RATE
)

# Battery
battery = Battery(
    config.PINS['I2C_SDA'],
    config.PINS['I2C_SCL']
)

# Network
network = Network(
    config.WIFI_SSID,
    config.WIFI_PASSWORD,
    config.SERVER_HOST,
    config.SERVER_PORT,
    config.SERVER_ENDPOINT
)

# SD Card (for backup when WiFi fails)
try:
    sd = SDCard(
        config.PINS['SD_CS'],
        config.PINS['SD_MOSI'],
        config.PINS['SD_MISO'],
        config.PINS['SD_CLK']
    )
except Exception as e:
    print(f"[SD] Not available: {e}")
    sd = None

# ============================================================================
# Connect to WiFi
# ============================================================================
print("[INIT] Connecting to WiFi...")
led.blue_on()

if network.connect(config.WIFI_CONNECT_TIMEOUT):
    print("[INIT] WiFi connected successfully!")
    led.green_on()
else:
    print("[INIT] WiFi connection failed!")
    led.set(True, False, False)  # Red = error
    time.sleep(2)

# Initial battery reading
battery.print_data(status)

print("\n[READY] Press RECORD button to start recording")
print("[READY] Waiting for GPS fix...\n")

# ============================================================================
# Main Loop
# ============================================================================
is_recording = False
last_gps_update = time.ticks_ms()
last_battery_update = time.ticks_ms()
last_status_print = time.ticks_ms()
last_send_time = time.ticks_ms()

# Pre-fetch data
gps_data = gps.get_data()
battery_data = battery.get_data(status)

try:
    while True:
        now = time.ticks_ms()
        
        # ========================================
        # Button Handling
        # ========================================
        if btn_record.was_pressed():
            is_recording = not is_recording
            
            if is_recording:
                print("\n[RECORD] *** RECORDING STARTED ***")
                led.red_on()
                
                # Check prerequisites
                if not network.is_connected():
                    print("[WARNING] Not connected to WiFi!")
                if not gps.has_fix():
                    print("[WARNING] No GPS fix yet!")
            else:
                print("\n[RECORD] *** RECORDING STOPPED ***")
                led.green_on()
        
        # ========================================
        # GPS Update
        # ========================================
        gps.update()
        
        if time.ticks_diff(now, last_gps_update) > config.GPS_UPDATE_INTERVAL:
            last_gps_update = now
            gps_data = gps.get_data()
            
            if config.DEBUG_GPS_DATA and gps.has_fix():
                gps.print_data()
        
        # ========================================
        # Battery Update
        # ========================================
        if time.ticks_diff(now, last_battery_update) > config.BATTERY_UPDATE_INTERVAL:
            last_battery_update = now
            battery_data = battery.get_data(status)
            
            if config.DEBUG_BATTERY_DATA:
                battery.print_data(status)
            
            # Check critical battery
            if battery_data['is_critical'] and is_recording:
                print("[WARNING] Critical battery! Stopping recording.")
                is_recording = False
                led.green_on()
        
        # ========================================
        # WiFi Reconnect
        # ========================================
        if not network.is_connected():
            if is_recording:
                print("[WARNING] WiFi disconnected during recording!")
            
            led.blue_on()
            if network.connect(10):
                led.green_on() if not is_recording else led.red_on()
        
        # ========================================
        # Audio Recording
        # ========================================
        if is_recording:
            # Continuously sample audio
            audio.sample()  # Returns True when buffer full
            
            # Send every second (buffer fills every 1 second with 16000 samples)
            if time.ticks_diff(now, last_send_time) >= config.AUDIO_SEND_INTERVAL:
                audio_buffer = audio.get_buffer()
                
                if audio_buffer and network.is_connected():
                    # Get audio stats
                    if config.DEBUG_AUDIO_STATS:
                        stats = audio.get_stats()
                        print(f"[AUDIO] Peak-to-peak: {stats['peak_to_peak']} "
                              f"({stats['utilization']:.1f}% of range)")
                    
                    # Send packet (10 seconds of audio = 160,000 samples)
                    print(f"[SEND] Sending {len(audio_buffer)} samples (10 sec), "
                          f"GPS: {'VALID' if gps_data['has_fix'] else 'NO FIX'}, "
                          f"Battery: {battery_data['soc']:.1f}%")
                    
                    success = network.send_audio_packet(
                        config.DEVICE_ID,
                        time.ticks_ms(),
                        audio_buffer,
                        config.AUDIO_SAMPLE_RATE,
                        gps_data,
                        battery_data
                    )
                    
                    last_send_time = now
                    
                    if success:
                        # Quick green blink
                        led.off()
                        time.sleep_ms(50)
                        led.red_on()
                    else:
                        # WiFi send failed - save to SD card as backup
                        if sd and sd.is_mounted():
                            print("[BACKUP] WiFi failed, saving to SD card...")
                            sd.save_audio_backup(
                                config.DEVICE_ID,
                                time.ticks_ms(),
                                audio_buffer,
                                gps_data,
                                battery_data
                            )
                        
                        # Error blink
                        for _ in range(2):
                            led.off()
                            time.sleep_ms(50)
                            led.red_on()
                            time.sleep_ms(50)
        
        # ========================================
        # Status Report
        # ========================================
        if time.ticks_diff(now, last_status_print) > 30000:  # Every 30 seconds
            last_status_print = now
            
            print("\n" + "="*40)
            print("STATUS REPORT")
            print("="*40)
            print(f"Uptime: {time.ticks_ms() // 1000} seconds")
            print(f"State: {'RECORDING' if is_recording else 'IDLE'}")
            print(f"Free RAM: {gc.mem_free()} bytes")
            
            network.print_stats()
            
            print(f"[GPS] Fix: {'YES' if gps.has_fix() else 'NO'}, "
                  f"Sats: {gps_data['satellites']}")
            if gps.has_fix():
                print(f"[GPS] {gps_data['latitude']:.6f}, {gps_data['longitude']:.6f}")
            
            battery.print_data(status)
            
            print("="*40 + "\n")
        
        # Small delay to prevent tight loop
        time.sleep_ms(1)

except KeyboardInterrupt:
    print("\n[EXIT] Stopped by user")
    led.off()

except Exception as e:
    print(f"\n[ERROR] Exception: {e}")
    import sys
    sys.print_exception(e)
    led.set(True, False, False)  # Red for error

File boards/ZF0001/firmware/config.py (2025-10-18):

"""
ZF0001 Configuration
Edit these values for your setup
"""

# WiFi Configuration
WIFI_SSID = "YourWiFiSSID"
WIFI_PASSWORD = "YourWiFiPassword"

# Server Configuration
SERVER_HOST = "192.168.1.100"  # Your server IP
SERVER_PORT = 8080
SERVER_ENDPOINT = "/api/audio"

# Device Configuration
DEVICE_ID = "ZF0001-00001"  # Unique device identifier

# Pin Configuration (hardware-specific)
PINS = {
    # Audio
    'MIC_ADC': 1,           # GPIO1 - ADC for microphone
    
    # GPS
    'GPS_TX': 15,           # GPIO15 - ESP32 TX -> GNSS RX
    'GPS_RX': 16,           # GPIO16 - ESP32 RX <- GNSS TX
    
    # I2C (Fuel Gauge)
    'I2C_SDA': 21,          # GPIO21
    'I2C_SCL': 47,          # GPIO47
    'I2C_FREQ': 100000,     # 100kHz (recommended for 10kΩ pull-ups)
    
    # LEDs
    'LED_RED': 4,           # GPIO4
    'LED_GREEN': 5,         # GPIO5
    'LED_BLUE': 6,          # GPIO6
    
    # Buttons
    'BTN_RECORD': 2,        # GPIO2 - Record button
    'BTN_BOOT': 0,          # GPIO0 - Boot button
    
    # Status
    'CHG_STAT': 7,          # GPIO7 - Charger status
    'PG_STAT': 8,           # GPIO8 - Power good
    'FG_ALERT': 9,          # GPIO9 - Fuel gauge alert
    
    # SD Card (optional)
    'SD_CS': 10,
    'SD_MOSI': 11,
    'SD_CLK': 12,
    'SD_MISO': 13,
    'SD_DETECT': 14,
    'SD_FREQ': 4000000,     # 4MHz SPI clock (limit for EMI and power consumption)
}

# Audio Configuration
AUDIO_SAMPLE_RATE = 16000   # 16kHz
AUDIO_BUFFER_SIZE = 160000  # 160,000 samples = 10 seconds of audio (~320KB fits in RAM)
AUDIO_SEND_INTERVAL = 10000  # Send every 10 seconds (ms)

# GPS Configuration
GPS_BAUD_RATE = 9600
GPS_UPDATE_INTERVAL = 1000  # Update every 1 second (ms)

# Battery Configuration
BATTERY_UPDATE_INTERVAL = 5000  # Update every 5 seconds (ms)
BATTERY_LOW_THRESHOLD = 20      # 20% warning
BATTERY_CRITICAL_THRESHOLD = 10 # 10% critical

# Network Configuration
HTTP_TIMEOUT = 10  # seconds
WIFI_CONNECT_TIMEOUT = 20  # seconds

# Debug Configuration
DEBUG = True
DEBUG_AUDIO_STATS = True
DEBUG_GPS_DATA = True
DEBUG_BATTERY_DATA = True

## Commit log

2025-10-17 lets see how good claude sonnet 4.5 is
    [layout.kicad_pcb]
2025-10-18 schematic ui
2025-10-18 ui schematic

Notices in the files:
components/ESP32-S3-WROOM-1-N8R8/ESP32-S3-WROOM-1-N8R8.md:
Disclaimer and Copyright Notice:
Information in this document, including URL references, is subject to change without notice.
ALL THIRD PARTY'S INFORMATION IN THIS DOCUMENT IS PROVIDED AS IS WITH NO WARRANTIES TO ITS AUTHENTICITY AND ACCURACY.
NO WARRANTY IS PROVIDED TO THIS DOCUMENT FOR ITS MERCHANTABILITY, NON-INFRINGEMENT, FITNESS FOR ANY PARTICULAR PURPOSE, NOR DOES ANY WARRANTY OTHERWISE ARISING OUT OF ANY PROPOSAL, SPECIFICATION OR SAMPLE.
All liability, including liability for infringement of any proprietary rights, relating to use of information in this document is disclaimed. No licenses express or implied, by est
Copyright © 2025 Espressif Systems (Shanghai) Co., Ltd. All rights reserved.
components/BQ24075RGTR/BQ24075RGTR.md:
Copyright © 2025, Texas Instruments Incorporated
